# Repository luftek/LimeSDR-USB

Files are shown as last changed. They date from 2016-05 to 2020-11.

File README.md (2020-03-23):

#### Enclosure KIT for now available on eBay
##### [https://www.ebay.com/itm/113327856684](https://www.ebay.com/itm/113327856684)
##### -> More design files and photos in: [hardware/enclosure/](./hardware/enclosure/)

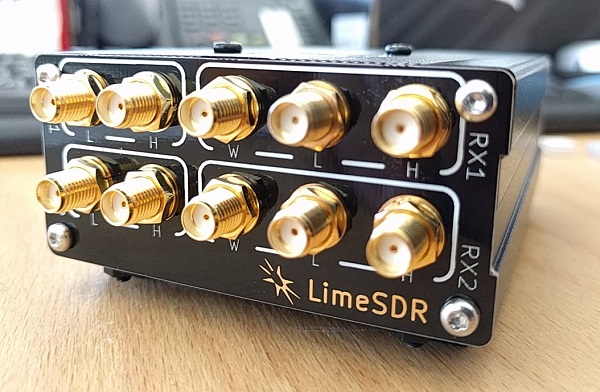
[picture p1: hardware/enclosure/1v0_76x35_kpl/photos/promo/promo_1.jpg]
Kit_promo_1


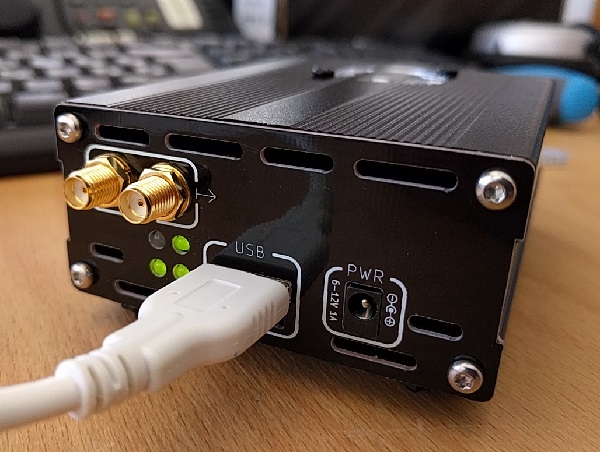
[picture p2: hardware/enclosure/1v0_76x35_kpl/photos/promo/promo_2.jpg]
Kit_promo_2


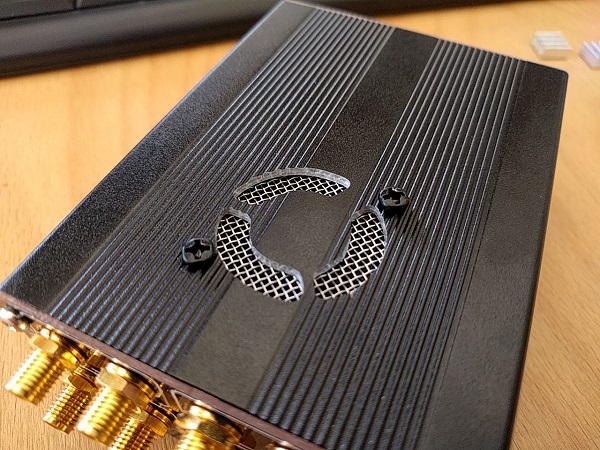
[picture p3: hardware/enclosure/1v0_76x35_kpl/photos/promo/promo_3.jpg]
Kit_promo_3


## Licensing

The hardware designs are licensed under a Creative Commons Attribution 3.0 Unported licence.

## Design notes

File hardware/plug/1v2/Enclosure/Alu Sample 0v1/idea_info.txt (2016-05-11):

Already available suitable enclosures?
Decided for higher 43mm enclosure to fit all 10 SMA connectors on front panel

Sample PCB:
1. main sample board in two parts 50x60, to see how it fits in Sample enclosure
2. Front and back panel with suitable ports, leds and dip switches

100x100 mm board samples from Dirty PCB?

TODO:
- design sample PCB to accomodate all connectors that are present currently on LimeSDR
- design Front panel
	-	10x SMA connectors
	-	status leds
- and Back panel
	-	1X SMA for clock
	-   DIP
	-   LEDs
	- 	FPGA I/O

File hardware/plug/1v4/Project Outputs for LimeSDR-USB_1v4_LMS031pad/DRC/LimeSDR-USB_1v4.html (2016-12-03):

Altium

# Design Rule Verification Report

Date: | | 2016-09-13
Time: | | 16:37:09
Elapsed Time: | | 00:03:49
Filename: | | E:\Saniok\Lime Micro\Lime PCBs\LimeSDR-USB_1v4\Altium designer design files\PCB\LimeSDR-USB_1v4.PcbDoc

Warnings: | | 12
Rule Violations: | | 0

## Summary

Warnings | Count
Unplated multi-layer pad(s) detected | 12
Total | 12

Rule Violations | Count
Component Clearance Constraint ( Horizontal Gap = -2mm, Vertical Gap = Infinite ) (InComponent('J13')),(InComponent('J14')) | 0
Component Clearance Constraint ( Horizontal Gap = -2mm, Vertical Gap = Infinite ) (InComponent('J17')),(All) | 0
Differential Pairs Uncoupled Length using the Gap Constraints (Min=0.1mm) (Max=0.2mm) (Prefered=0.1mm) and Width Constraints (Min=0.1mm) (Max=0.4mm) (Prefered=0.1mm) (InNet('FX3_XTAL_N') or InNet('FX3_XTAL_P')) | 0
Matched Lengths(Tolerance=0.5mm) (InNetClass('DDR2_1_A[0..12]')) | 0
Matched Lengths(Tolerance=0.5mm) (InNetClass('DDR2_1_DQ[0..15]')) | 0
Matched Lengths(Tolerance=0.5mm) (InNetClass('DDR2_2_A[0..12]')) | 0
Matched Lengths(Tolerance=0.5mm) (InNetClass('DDR2_2_DQ[0..15]')) | 0
Net Antennae (Tolerance=0mm) (All) | 0
Hole To Hole Clearance (Gap=0.15mm) (All),(All) | 0
Routing Layers(All) | 0
Clearance Constraint (Gap=0.1mm) (All),(All) | 0
Short-Circuit Constraint (Allowed=No) (All),(All) | 0
Un-Routed Net Constraint ( (All) ) | 0
Power Plane Connect Rule(Relief Connect )(Expansion=0.508mm) (Conductor Width=0.254mm) (Air Gap=0.254mm) (Entries=4) (All) | 0
Width Constraint (Min=0.1mm) (Max=5mm) (Preferred=0.2mm) (All) | 0
Routing Via (MinHoleWidth=0.2mm) (MaxHoleWidth=4.5mm) (PreferredHoleWidth=0.2mm) (MinWidth=0.31mm) (MaxWidth=5mm) (PreferedWidth=0.4mm) (All) | 0
Pads and Vias to follow the Drill pairs settings | 0
Hole Size Constraint (Min=0.2mm) (Max=10mm) (All) | 0
Height Constraint (Min=0mm) (Max=14.47mm) (Prefered=14.47mm) (OnTopLayer) | 0
Differential Pairs Uncoupled Length using the Gap Constraints (Min=0.1mm) (Max=0.3mm) (Prefered=0.1mm) and Width Constraints (Min=0.1mm) (Max=0.5mm) (Prefered=0.2mm) (All) | 0
Component Clearance Constraint ( Horizontal Gap = 0.01mm, Vertical Gap = 0.254mm ) (All),(All) | 0
Height Constraint (Min=0mm) (Max=2.67mm) (Prefered=2.67mm) (OnBottomLayer) | 0
Modified Polygon (Allow modified: No), (Allow shelved: No) | 0
Differential Pairs Uncoupled Length using the Gap Constraints (Min=0.1mm) (Max=0.2mm) (Prefered=0.1mm) and Width Constraints (Min=0.1mm) (Max=0.4mm) (Prefered=0.1mm) (InNetClass('DDR2_1_CK') or InNetClass('DDR2_1_CK')) | 0
Matched Lengths(Tolerance=1mm) (InNetClass('LMS_PORT1')) | 0
Matched Lengths(Tolerance=1mm) (InNetClass('LMS_PORT2')) | 0
Differential Pairs Uncoupled Length using the Gap Constraints (Min=0.1mm) (Max=0.3mm) (Prefered=0.1mm) and Width Constraints (Min=0.2mm) (Max=0.2mm) (Prefered=0.2mm) (InNetClass('FX3_DATA')) | 0
Differential Pairs Uncoupled Length using the Gap Constraints (Min=0.1mm) (Max=0.3mm) (Prefered=0.2mm) and Width Constraints (Min=0.1mm) (Max=0.3mm) (Prefered=0.2mm) (InNetClass('TX_RF')) | 0
Differential Pairs Uncoupled Length using the Gap Constraints (Min=0.1mm) (Max=0.3mm) (Prefered=0.2mm) and Width Constraints (Min=0.1mm) (Max=0.3mm) (Prefered=0.2mm) (InNetClass('RX_RF')) | 0
Width Constraint (Min=0.1mm) (Max=7mm) (Preferred=0.2mm) (All) | 0
Component Clearance Constraint ( Horizontal Gap = -1mm, Vertical Gap = Infinite ) (InComponent('LEDS1') or InComponent('LEDS2') or InComponent('LED1') or InComponent('LED4') or InComponent('LED5') or InComponent('LED8')),(InComponent('LED1') or InComponent('LED4') or InComponent('LED5') or InComponent('LED8') or InComponent('LEDS1') or InComponent('LEDS2')) | 0
Total | 0

## Warnings

Unplated multi-layer pad(s) detected

Pad Free-2(78.5mm,60.1mm) on MultiLayer on Net GND

Pad Free-3(79.7mm,60.1mm) on MultiLayer on Net GND

Pad Free-4(80.875mm,60.1mm) on MultiLayer on Net GND

Pad Free-4(80.875mm,-0.1mm) on MultiLayer on Net GND

Pad Free-3(79.7mm,-0.1mm) on MultiLayer on Net GND

Pad Free-2(78.5mm,-0.1mm) on MultiLayer on Net GND

Pad Free-2(21.5mm,-0.1mm) on MultiLayer on Net GND

Pad Free-3(20.3mm,-0.1mm) on MultiLayer on Net GND

Pad Free-4(19.125mm,-0.1mm) on MultiLayer on Net GND

Pad Free-2(21.5mm,60.1mm) on MultiLayer on Net GND

Pad Free-3(20.3mm,60.1mm) on MultiLayer on Net GND

Pad Free-4(19.125mm,60.1mm) on MultiLayer on Net GND

Back to top

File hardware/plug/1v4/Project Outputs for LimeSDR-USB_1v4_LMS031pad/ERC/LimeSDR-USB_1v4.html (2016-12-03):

Altium

# Electrical Rule Check Report

Date: | | 2016-09-13
Time: | | 16:41:00
Filename: | | E:\Saniok\Lime Micro\Lime PCBs\LimeSDR-USB_1v4\Altium designer design files\Project Outputs for LimeSDR-USB_1v4\ERC\LimeSDR-USB_1v4.html

Class | Document | Message
Warning | 15_BoardPowerSupply.SchDoc | FPGA_LED1_R contains IO Pin and Power Pin objects (Pin LED1-3,Pin IC8-E3,Pin LEDS1-K1)
Warning | 15_BoardPowerSupply.SchDoc | FPGA_LED2_R contains IO Pin and Power Pin objects (Pin LED7-3,Pin IC8-E1,Pin LEDS1-K2)
Warning | 15_BoardPowerSupply.SchDoc | FX3_LED_R contains IO Pin and Power Pin objects (Pin LED2-3,Pin IC8-H5,Pin LEDS2-K1)

Warning

15_BoardPowerSupply.SchDoc

GND contains IO Pin and Power Pin objects (Pin LED8-3,Pin IC19-4,Pin IC22-5,Pin IC13-A1,Pin IC8-A1,Pin IC12-A3,Pin IC11-A3,Pin IC12-A7,Pin IC11-A7,Pin IC13-A8,Pin IC8-A19,Pin IC8-A22,Pin IC8-AA2,Pin IC8-AA22,Pin IC8-AB1,Pin IC8-AB6,Pin IC8-AB22,Pin IC12-B2,Pin IC11-B2,Pin IC8-B5,Pin IC13-B7,Pin IC13-B8,Pin IC12-B8,Pin IC11-B8,Pin IC13-B9,Pin IC8-B19,Pin IC8-C5,Pin IC8-C9,Pin IC8-C10,Pin IC8-C11,Pin IC8-C12,Pin IC8-C14,Pin IC8-C15,Pin IC8-C16,Pin IC8-C18,Pin IC12-D2,Pin IC11-D2,Pin IC8-D3,Pin IC8-D6,Pin IC13-D8,Pin IC12-D8,Pin IC11-D8,Pin IC8-D8,Pin IC8-D15,Pin IC8-D17,Pin IC8-D20,Pin IC13-E2,Pin IC12-E3,Pin IC11-E3,Pin IC12-E7,Pin IC11-E7,Pin IC8-E9,Pin IC8-E13,Pin IC8-E18,Pin IC8-E20,Pin IC12-F2,Pin IC11-F2,Pin IC8-F3,Pin IC8-F5,Pin IC12-F8,Pin IC11-F8,Pin IC8-F12,Pin IC8-F19,Pin IC8-F20,Pin IC13-G1,Pin IC8-G2,Pin IC13-G11,Pin IC8-G20,Pin IC12-H2,Pin IC11-H2,Pin IC8-H3,Pin IC12-H8,Pin IC11-H8,Pin IC8-H12,Pin IC8-H13,Pin IC8-H17,Pin IC8-H18,Pin IC12-J3,Pin IC11-J3,Pin IC12-J7,Pin IC11-J7,Pin IC8-J9,Pin IC8-J15,Pin IC8-J18,Pin IC8-J19,Pin LEDS2-K2,Pin IC13-K3,Pin IC8-K3,Pin IC13-K4,Pin IC8-K10,Pin IC8-K11,Pin IC8-K12,Pin IC8-K13,Pin IC8-K16,Pin IC8-K19,Pin IC13-L1,Pin IC13-L2,Pin IC13-L3,Pin IC13-L6,Pin IC8-L10,Pin IC13-L11,Pin IC8-L11,Pin IC8-L12,Pin IC8-L13,Pin IC8-L15,Pin IC8-L20,Pin IC8-M10,Pin IC8-M11,Pin IC8-M12,Pin IC8-M13,Pin IC8-M16,Pin IC12-N1,Pin IC11-N1,Pin IC8-N3,Pin IC8-N10,Pin IC8-N11,Pin IC8-N12,Pin IC8-N13,Pin IC8-N15,Pin IC8-P8,Pin IC12-P9,Pin IC11-P9,Pin IC8-P19,Pin IC8-P20,Pin IC8-R3,Pin IC8-R9,Pin IC8-R11,Pin IC8-R13,Pin IC8-R17,Pin IC8-T17,Pin IC8-T20,Pin IC8-U3,Pin IC8-U5,Pin IC8-V18,Pin IC8-V20,Pin IC8-W3,Pin IC8-W19,Pin IC8-Y5,Pin IC8-Y9,Pin IC8-Y11,Pin IC8-Y12,Pin IC8-Y15,Pin IC8-Y16,Pin IC8-Y18,Pin IC8-Y20)
Warning | 10_FPGA_misc.SchDoc | Net FPGA_JTAG_TCK has no driving source (Pin IC8-L2,Pin J11-1,Pin R62-1)
Warning | 10_FPGA_misc.SchDoc | Net FPGA_JTAG_TDI has no driving source (Pin IC8-L5,Pin J11-9,Pin R58-1)
Warning | 10_FPGA_misc.SchDoc | Net FPGA_JTAG_TMS has no driving source (Pin IC8-L1,Pin J11-5,Pin R55-1)
Warning | 12_USB3_0_device.SchDoc | Net FPGA_NCONFIG has no driving source (Pin IC8-K5,Pin R105-2,Pin R106-2)
Warning | 12_USB3_0_device.SchDoc | Net FX3_FSLC0 has no driving source (Pin IC13-B2,Pin R125-2)
Warning | 12_USB3_0_device.SchDoc | Net FX3_FSLC1 has no driving source (Pin IC13-B4,Pin R127-2)
Warning | 12_USB3_0_device.SchDoc | Net FX3_FSLC2 has no driving source (Pin IC13-E6,Pin R128-2)
Warning | 12_USB3_0_device.SchDoc | Net FX3_JTAG_TCK has no driving source (Pin IC13-F6,Pin J16-4)
Warning | 12_USB3_0_device.SchDoc | Net FX3_JTAG_TDI has no driving source (Pin IC13-E7,Pin J16-8)
Warning | 12_USB3_0_device.SchDoc | Net FX3_JTAG_TMS has no driving source (Pin IC13-E8,Pin J16-2)
Warning | 12_USB3_0_device.SchDoc | Net FX3_JTAG_TRST has no driving source (Pin IC13-B11,Pin R124-1)
Warning | 12_USB3_0_device.SchDoc | Net FX3_OTG_ID has no driving source (Pin IC13-C9,Pin J15-4,Pin R92-2)
Warning | 12_USB3_0_device.SchDoc | Net FX3_PCLK has no driving source (Pin IC8-T21,Pin R98-1)
Warning | 12_USB3_0_device.SchDoc | Net FX3_RST has no driving source (Pin C278-1,Pin IC13-C5,Pin R118-1,Pin R120-2,Pin SW1-2)
Warning | 12_USB3_0_device.SchDoc | Net FX3_USB_SSRX_N has no driving source (Pin IC13-A4,Pin IC14-4,Pin IC14-7,Pin J15-9)
Warning | 12_USB3_0_device.SchDoc | Net FX3_USB_SSRX_P has no driving source (Pin IC13-A3,Pin IC14-5,Pin IC14-6,Pin J15-10)
Warning | 14_Clocks.SchDoc | Net LMK_CLK has no driving source (Pin IC8-B12,Pin IC20-15)
Warning | 04_LMS7002M_Misc.SchDoc | Net LMS_MCLK1 has no driving source (Pin IC1-AB34,Pin IC8-G21)
Warning | 10_FPGA_misc.SchDoc | Net LMS_MCLK2 has no driving source (Pin IC1-P34,Pin IC8-B11)
Warning | 10_FPGA_misc.SchDoc | Net MSEL0 has no driving source (Pin IC8-M17,Pin R51-1,Pin R52-2)
Warning | 10_FPGA_misc.SchDoc | Net MSEL1 has no driving source (Pin IC8-L18,Pin R53-1,Pin R54-2)
Warning | 10_FPGA_misc.SchDoc | Net MSEL2 has no driving source (Pin IC8-L17,Pin R56-1,Pin R57-2)
Warning | 10_FPGA_misc.SchDoc | Net MSEL3 has no driving source (Pin IC8-K20,Pin R59-1,Pin R60-2)
Warning | 05_LMS7002M_RF1.SchDoc | Net NetC10_1 has no driving source (Pin C10-1,Pin IC4-5)
Warning | 05_LMS7002M_RF1.SchDoc | Net NetC19_1 has no driving source (Pin C19-1,Pin IC5-5)
Warning | 06_LMS7002M_RF2.SchDoc | Net NetC30_1 has no driving source (Pin C30-1,Pin IC6-5)
Warning | 06_LMS7002M_RF2.SchDoc | Net NetC39_1 has no driving source (Pin C39-1,Pin IC7-5)
Warning | 15_BoardPowerSupply.SchDoc | Net NetC383_2 has no driving source (Pin C383-2,Pin FR58-2,Pin IC28-5,Pin IC28-8)
Warning | 15_BoardPowerSupply.SchDoc | Net NetC397_2 has no driving source (Pin C397-2,Pin FR59-2,Pin IC30-5,Pin IC30-8)
Warning | 15_BoardPowerSupply.SchDoc | Net NetC404_2 has no driving source (Pin C404-2,Pin FR60-2,Pin IC33-5,Pin IC33-8)
Warning | 15_BoardPowerSupply.SchDoc | Net NetC420_2 has no driving source (Pin C420-2,Pin FR62-2,Pin IC36-3)
Warning | 15_BoardPowerSupply.SchDoc | Net NetC421_2 has no driving source (Pin C421-2,Pin IC36-1,Pin R211-2,Pin R212-1)
Warning | 15_BoardPowerSupply.SchDoc | Net NetIC36_8 has no driving source (Pin IC36-8,Pin R209-2,Pin R210-2)
Warning | 14_Clocks.SchDoc | Net SI_CLK0 has no driving source (Pin IC8-T2,Pin IC24-13)
Warning | 14_Clocks.SchDoc | Net SI_CLK1 has no driving source (Pin IC8-AA12,Pin IC24-12)
Warning | 14_Clocks.SchDoc | Net SI_CLK2 has no driving source (Pin IC8-AB12,Pin IC24-9)
Warning | 14_Clocks.SchDoc | Net SI_CLK3 has no driving source (Pin IC8-T22,Pin IC24-8)
Warning | 14_Clocks.SchDoc | Net SI_CLK5 has no driving source (Pin IC8-G1,Pin IC24-17)
Warning | 14_Clocks.SchDoc | Net SI_CLK6 has no driving source (Pin IC8-AA11,Pin IC24-16)
Warning | 14_Clocks.SchDoc | Net SI_CLK7 has no driving source (Pin IC8-AB11,Pin IC24-15)

Back to top

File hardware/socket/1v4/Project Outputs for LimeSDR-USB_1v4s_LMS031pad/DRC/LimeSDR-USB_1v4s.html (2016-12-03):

Altium

# Design Rule Verification Report

Date: | | 2016-09-13
Time: | | 17:07:08
Elapsed Time: | | 00:03:37
Filename: | | E:\Saniok\Lime Micro\Lime PCBs\LimeSDR-USB_1v4s\Altium designer design files\PCB\LimeSDR-USB_1v4s.PcbDoc

Warnings: | | 12
Rule Violations: | | 0

## Summary

Warnings | Count
Unplated multi-layer pad(s) detected | 12
Total | 12

Rule Violations | Count
Component Clearance Constraint ( Horizontal Gap = -1mm, Vertical Gap = Infinite ) (InComponent('LEDS1') or InComponent('LEDS2') or InComponent('LED1') or InComponent('LED4') or InComponent('LED5') or InComponent('LED8')),(InComponent('LED1') or InComponent('LED4') or InComponent('LED5') or InComponent('LED8') or InComponent('LEDS1') or InComponent('LEDS2')) | 0
Width Constraint (Min=0.1mm) (Max=7mm) (Preferred=0.2mm) (All) | 0
Differential Pairs Uncoupled Length using the Gap Constraints (Min=0.1mm) (Max=0.3mm) (Prefered=0.2mm) and Width Constraints (Min=0.1mm) (Max=0.3mm) (Prefered=0.2mm) (InNetClass('RX_RF')) | 0
Differential Pairs Uncoupled Length using the Gap Constraints (Min=0.1mm) (Max=0.3mm) (Prefered=0.2mm) and Width Constraints (Min=0.1mm) (Max=0.3mm) (Prefered=0.2mm) (InNetClass('TX_RF')) | 0
Differential Pairs Uncoupled Length using the Gap Constraints (Min=0.1mm) (Max=0.3mm) (Prefered=0.1mm) and Width Constraints (Min=0.2mm) (Max=0.2mm) (Prefered=0.2mm) (InNetClass('FX3_DATA')) | 0
Matched Lengths(Tolerance=1mm) (InNetClass('LMS_PORT2')) | 0
Matched Lengths(Tolerance=1mm) (InNetClass('LMS_PORT1')) | 0
Differential Pairs Uncoupled Length using the Gap Constraints (Min=0.1mm) (Max=0.2mm) (Prefered=0.1mm) and Width Constraints (Min=0.1mm) (Max=0.4mm) (Prefered=0.1mm) (InNetClass('DDR2_1_CK') or InNetClass('DDR2_1_CK')) | 0
Modified Polygon (Allow modified: No), (Allow shelved: No) | 0
Height Constraint (Min=0mm) (Max=2.67mm) (Prefered=2.67mm) (OnBottomLayer) | 0
Component Clearance Constraint ( Horizontal Gap = 0.01mm, Vertical Gap = 0.254mm ) (All),(All) | 0
Differential Pairs Uncoupled Length using the Gap Constraints (Min=0.1mm) (Max=0.3mm) (Prefered=0.1mm) and Width Constraints (Min=0.1mm) (Max=0.5mm) (Prefered=0.2mm) (All) | 0
Height Constraint (Min=0mm) (Max=14.47mm) (Prefered=14.47mm) (OnTopLayer) | 0
Hole Size Constraint (Min=0.2mm) (Max=10mm) (All) | 0
Pads and Vias to follow the Drill pairs settings | 0
Routing Via (MinHoleWidth=0.2mm) (MaxHoleWidth=4.5mm) (PreferredHoleWidth=0.2mm) (MinWidth=0.31mm) (MaxWidth=5mm) (PreferedWidth=0.4mm) (All) | 0
Width Constraint (Min=0.1mm) (Max=5mm) (Preferred=0.2mm) (All) | 0
Power Plane Connect Rule(Relief Connect )(Expansion=0.508mm) (Conductor Width=0.254mm) (Air Gap=0.254mm) (Entries=4) (All) | 0
Un-Routed Net Constraint ( (All) ) | 0
Short-Circuit Constraint (Allowed=No) (All),(All) | 0
Clearance Constraint (Gap=0.1mm) (All),(All) | 0
Routing Layers(All) | 0
Hole To Hole Clearance (Gap=0.15mm) (All),(All) | 0
Net Antennae (Tolerance=0mm) (All) | 0
Matched Lengths(Tolerance=0.5mm) (InNetClass('DDR2_2_DQ[0..15]')) | 0
Matched Lengths(Tolerance=0.5mm) (InNetClass('DDR2_2_A[0..12]')) | 0
Matched Lengths(Tolerance=0.5mm) (InNetClass('DDR2_1_DQ[0..15]')) | 0
Matched Lengths(Tolerance=0.5mm) (InNetClass('DDR2_1_A[0..12]')) | 0
Differential Pairs Uncoupled Length using the Gap Constraints (Min=0.1mm) (Max=0.2mm) (Prefered=0.1mm) and Width Constraints (Min=0.1mm) (Max=0.4mm) (Prefered=0.1mm) (InNet('FX3_XTAL_N') or InNet('FX3_XTAL_P')) | 0
Component Clearance Constraint ( Horizontal Gap = -2mm, Vertical Gap = Infinite ) (InComponent('J17')),(All) | 0
Component Clearance Constraint ( Horizontal Gap = -2mm, Vertical Gap = Infinite ) (InComponent('J13')),(InComponent('J14')) | 0
Total | 0

## Warnings

Unplated multi-layer pad(s) detected

Pad Free-4(19.125mm,60.1mm) on MultiLayer on Net GND

Pad Free-3(20.3mm,60.1mm) on MultiLayer on Net GND

Pad Free-2(21.5mm,60.1mm) on MultiLayer on Net GND

Pad Free-4(19.125mm,-0.1mm) on MultiLayer on Net GND

Pad Free-3(20.3mm,-0.1mm) on MultiLayer on Net GND

Pad Free-2(21.5mm,-0.1mm) on MultiLayer on Net GND

Pad Free-2(78.5mm,-0.1mm) on MultiLayer on Net GND

Pad Free-3(79.7mm,-0.1mm) on MultiLayer on Net GND

Pad Free-4(80.875mm,-0.1mm) on MultiLayer on Net GND

Pad Free-4(80.875mm,60.1mm) on MultiLayer on Net GND

Pad Free-3(79.7mm,60.1mm) on MultiLayer on Net GND

Pad Free-2(78.5mm,60.1mm) on MultiLayer on Net GND

Back to top

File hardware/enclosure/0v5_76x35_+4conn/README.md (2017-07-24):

[eBay listing](http://www.ebay.com/itm/-/112088499793) 

### fits great :)

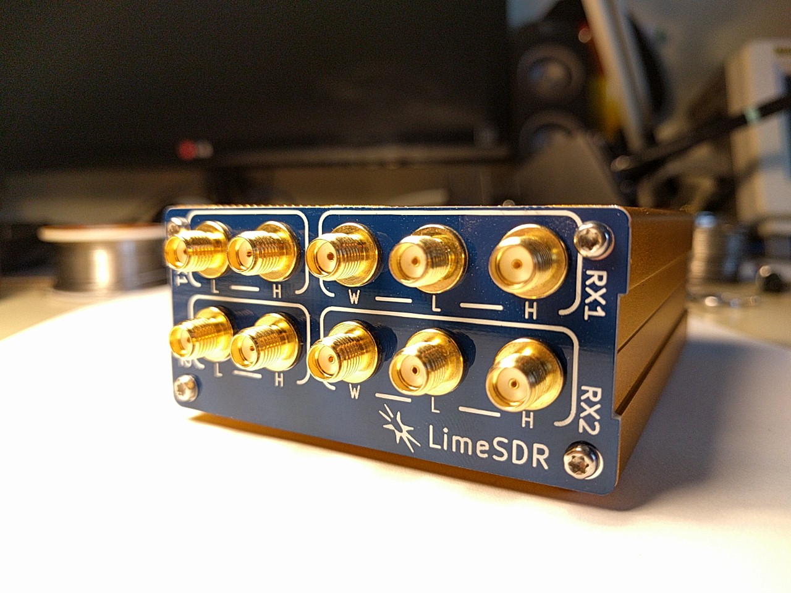
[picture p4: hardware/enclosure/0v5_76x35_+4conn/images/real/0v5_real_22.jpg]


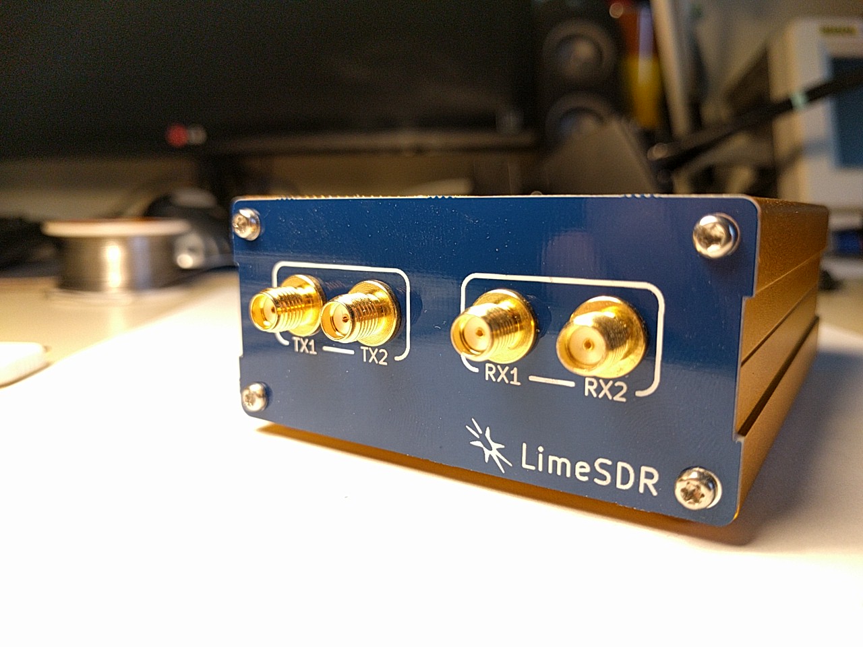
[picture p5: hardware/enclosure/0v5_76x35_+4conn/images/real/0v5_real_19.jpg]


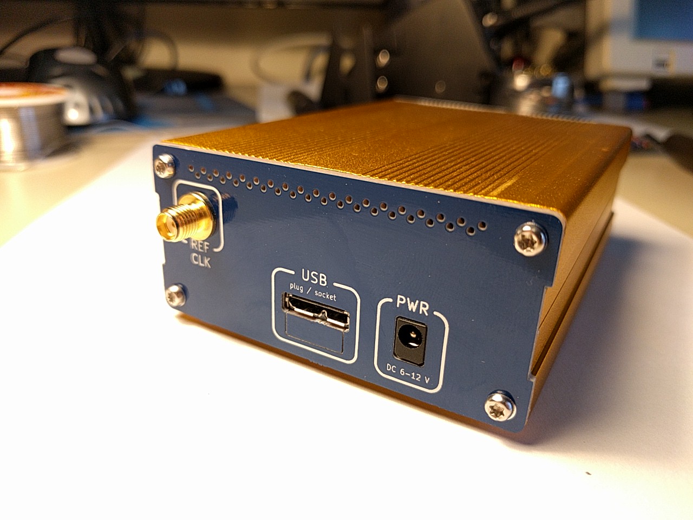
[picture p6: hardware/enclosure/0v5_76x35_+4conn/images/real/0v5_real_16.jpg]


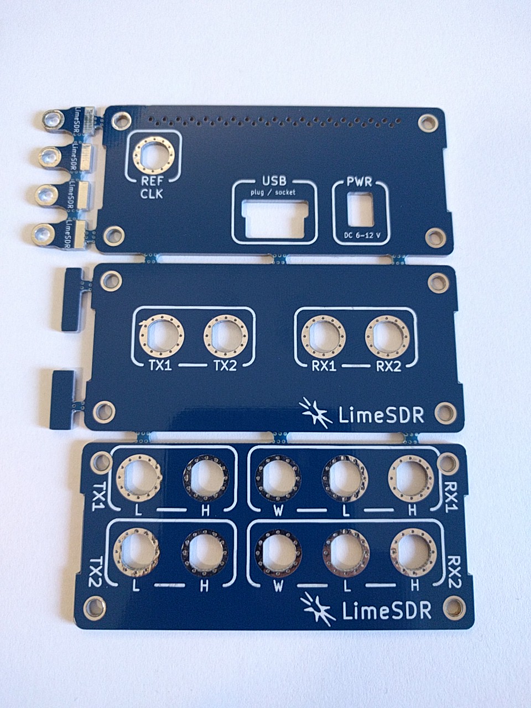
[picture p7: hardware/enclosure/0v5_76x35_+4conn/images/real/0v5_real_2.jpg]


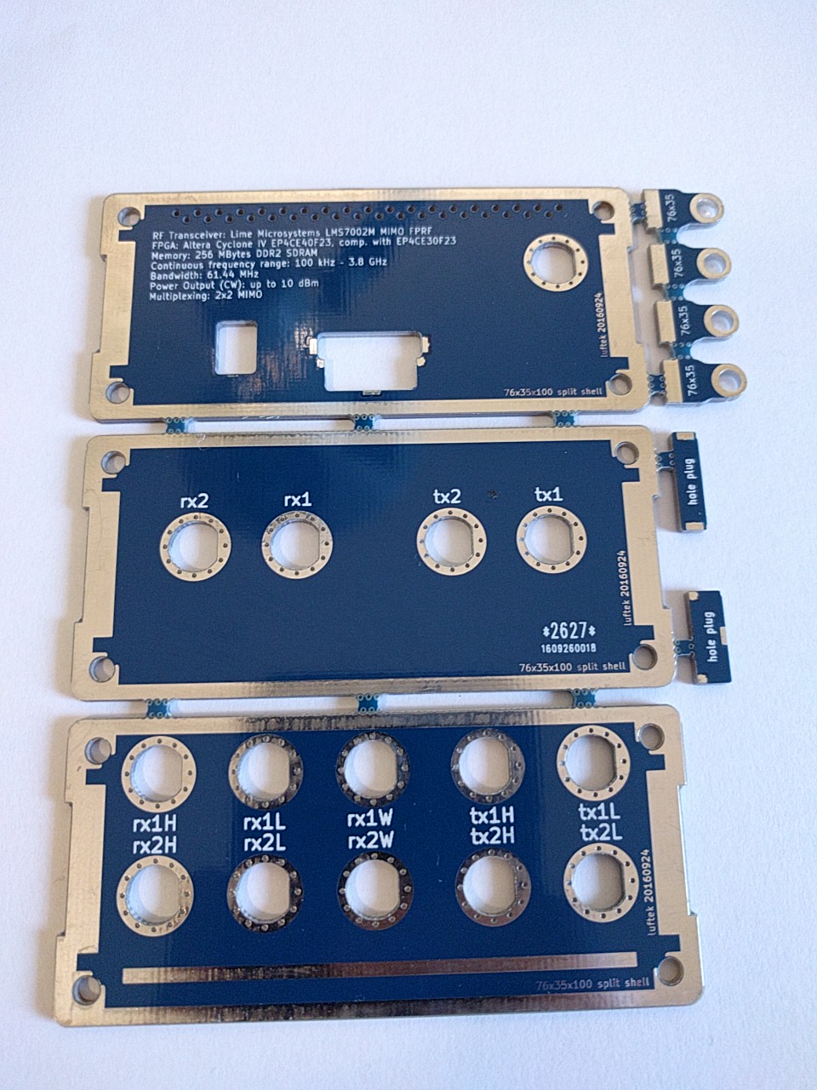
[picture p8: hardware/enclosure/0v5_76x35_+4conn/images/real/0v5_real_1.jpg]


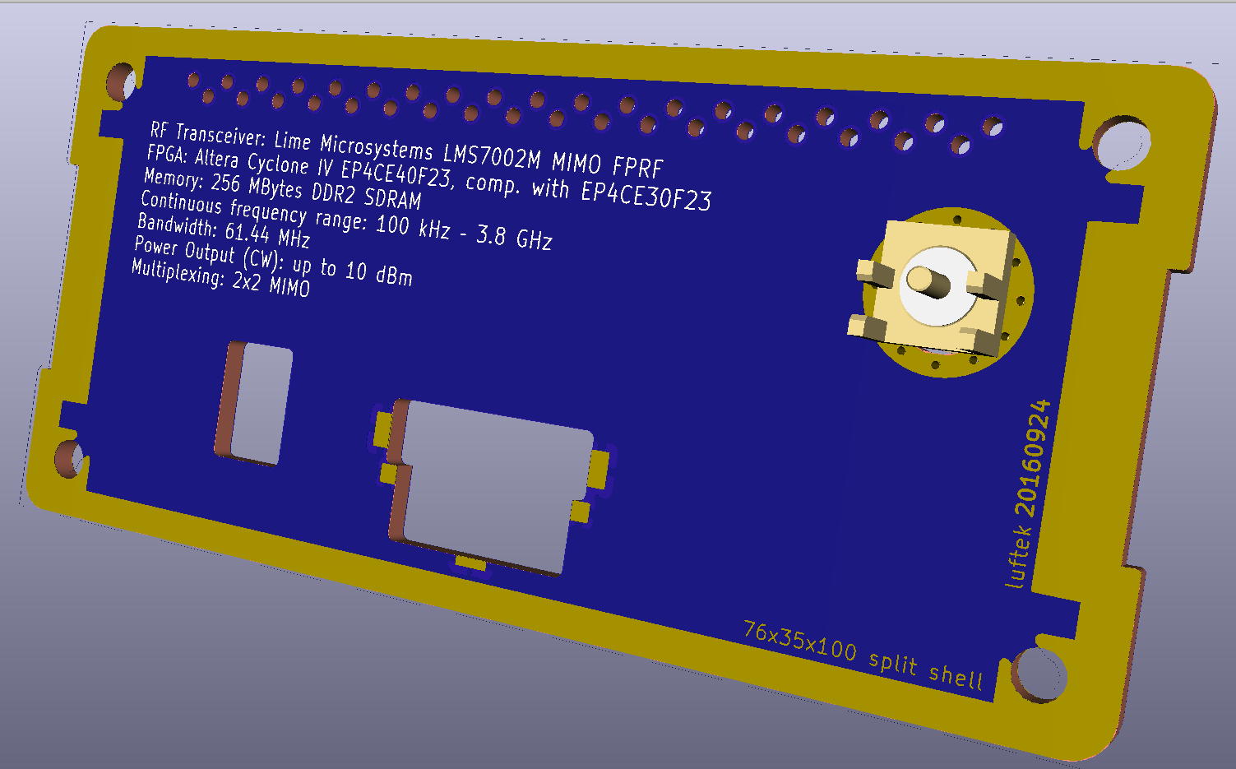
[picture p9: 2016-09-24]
hardware/enclosure/0v5_76x35_+4conn/images/design/2016-09-24_17_07_07-3D_Viewer.png

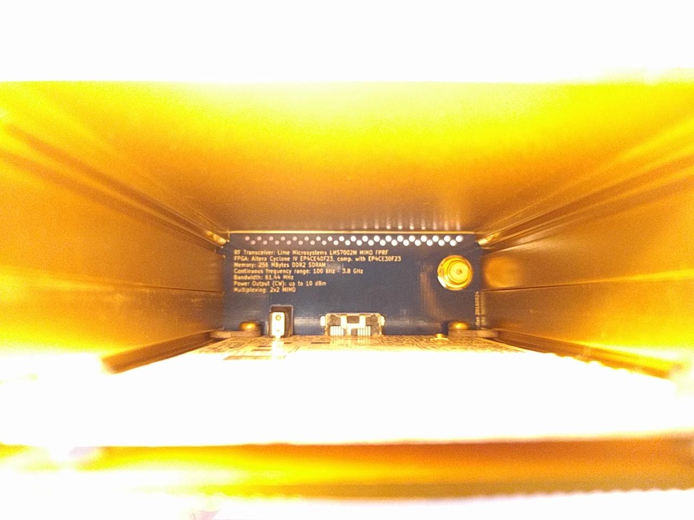
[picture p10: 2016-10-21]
hardware/enclosure/0v5_76x35_+4conn/images/real/0v5_real_21.jpg

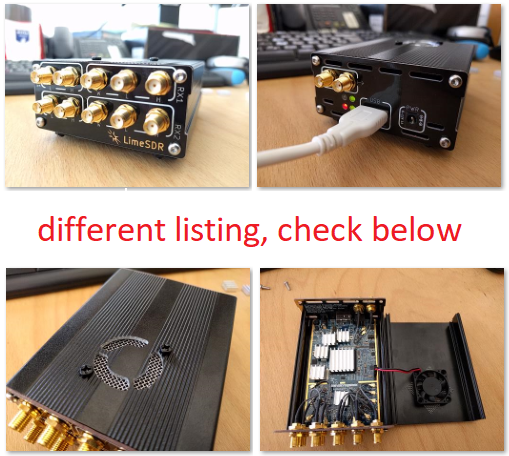
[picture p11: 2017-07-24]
hardware/enclosure/1v0_76x35_kpl/photos/promo/promo_.png

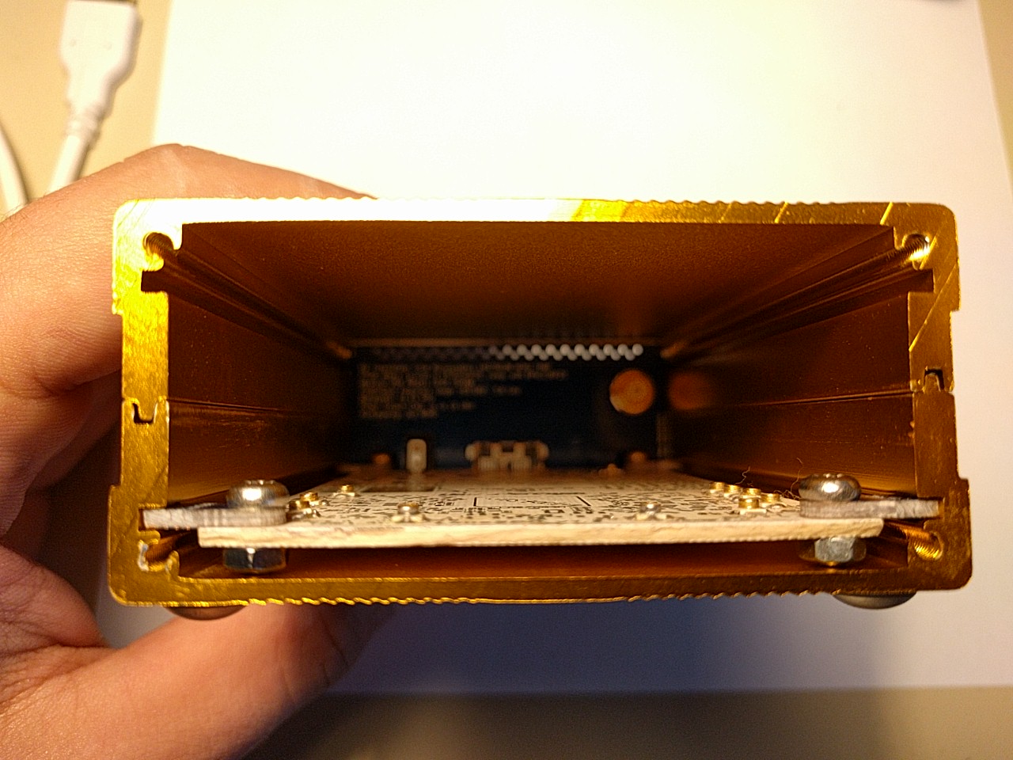
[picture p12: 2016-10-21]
hardware/enclosure/0v5_76x35_+4conn/images/real/0v5_real_20.jpg

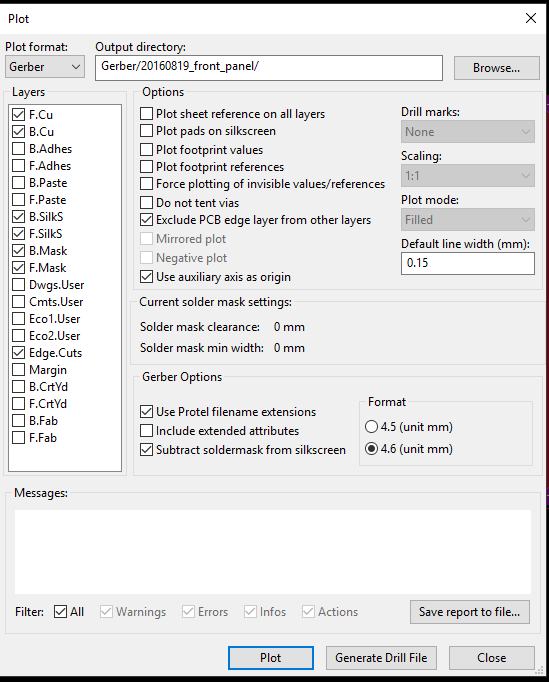
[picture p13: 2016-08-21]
hardware/enclosure/0v5_76x35_+4conn/images/design/2016-08-19 16_58_14-Pcbnew (2016-07-22 BZR 6991, Git 146a78a)-product C__Users_Borec_Documents_GitHu.png

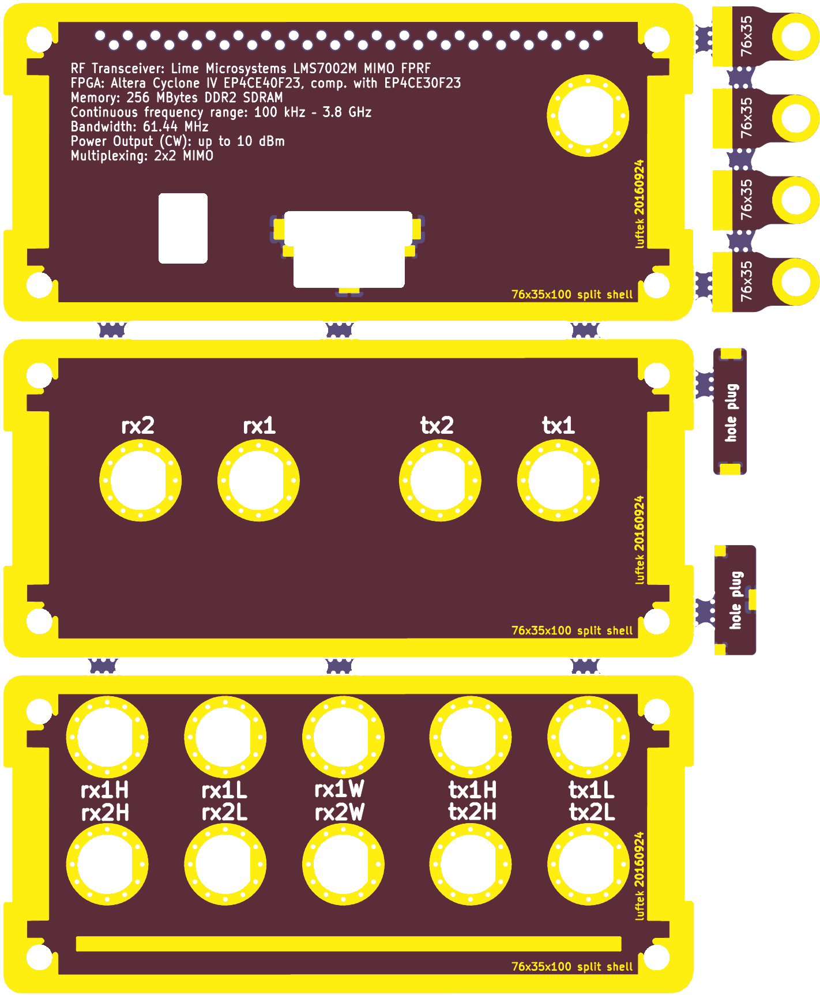
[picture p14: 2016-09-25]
hardware/enclosure/0v5_76x35_+4conn/images/design/20160924_combined_Combined_Top.png

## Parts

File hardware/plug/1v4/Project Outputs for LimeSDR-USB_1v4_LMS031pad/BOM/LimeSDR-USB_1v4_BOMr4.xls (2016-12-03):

Item # | Comment | Quantity | Designator | Footprint | Manufacturer | Manufacturer Part Number 1 | Supplier 1 | Supplier Part Number 1 | Part Description | Assembly Info
1 | 10pF, 25V | 4 | C1, C361, C362, C363 | CAP0402 | AVX | 04023A100JAT2A | Farnell | 2332478RL | 10pF ±5% 25V C0G, NP0 Ceramic Capacitor -55°C ~ 125°C Surface Mount, MLCC 0402 (1005 Metric) 0.039" L x 0.020" W (1.00mm x 0.50mm)
2 | 1uF, 10V | 22 | C2, C3, C118, C123, C130, C135, C140, C145, C242, C267, C326, C329, C333, C334, C341, C380, C382, C388, C394, C396, C403, C408 | CAP0402 | TDK | GRM155R61A105KE15J | Newark | 490-6298-2-ND | 1µF ±10% 10V X5R Ceramic Capacitor -55°C ~ 85°C Surface Mount, MLCC 0402 (1005 Metric) 0.039" L x 0.020" W (1.00mm x 0.50mm) | NF(C341)
3 | 100nF, 16V | 193 | C4, C5, C6, C7, C8, C24, C25, C26, C27, C28, C103, C104, C105, C106, C107, C108, C109, C110, C111, C112, C113, C114, C119, C124, C125, C131, C136, C141, C146, C147, C148, C149, C150, C151, C152, C153, C154, C155, C156, C157, C158, C159, C160, C161, C162, C163, C164, C165, C166, C167, C168, C169, C170, C171, C172, C173, C174, C175, C176, C177, C178, C179, C180, C181, C182, C183, C184, C185, C186, C187, C188, C189, C190, C191, C192, C193, C194, C195, C196, C197, C198, C199, C200, C201, C202, C203, C204, C205, C206, C207, C208, C209, C210, C211, C212, C213, C214, C215, C216, C217, C218, C219, C220, C221, C222, C223, C224, C226, C227, C228, C229, C232, C233, C234, C235, C236, C237, C238, C239, C243, C244, C246, C247, C248, C249, C251, C252, C253, C254, C257, C258, C259, C260, C261, C262, C263, C264, C268, C269, C270, C271, C272, C274, C276, C278, C279, C280, C281, C282, C284, C285, C288, C291, C293, C296, C299, C300, C302, C305, C306, C307, C308, C309, C310, C311, C312, C321, C322, C323, C327, C328, C330, C335, C338, C342, C345, C346, C352, C359, C360, C364, C365, C366, C372, C373, C378, C381, C395, C399, MN5, MN8, MN33, MN36 | CAP0402 | Murata Electronics | GRM155R71C104KA88D | Mouser | 81-GRM155R71C104KA88 | 0.10µF ±10% 16V X7R Ceramic Capacitor -55°C ~ 125°C Surface Mount, MLCC 0402 (1005 Metric) 0.039" L x 0.020" W (1.00mm x 0.50mm)
4 | 100pF, 50V | 35 | C9, C10, C13, C15, C16, C17, C18, C19, C20, C29, C30, C33, C35, C36, C37, C38, C39, C40, C331, C332, C336, C337, C339, C340, C343, C344, C347, C348, C349, C350, C351, MN25, MN28, MN53, MN56 | CAP0402 | Yageo | CC0402JRNPO9BN101 | Digi-Key | 311-1024-1-ND | 100pF ±5% 50V C0G, NP0 Ceramic Capacitor -55°C ~ 125°C Surface Mount, MLCC 0402 (1005 Metric) 0.039" L x 0.020" W (1.00mm x 0.50mm)
5 | 47pF | 10 | C11, C12, C21, C22, C31, C32, C41, C42, C324, C325 | CAP0402 | TDK Corporation | C1005C0G1H470F050BA | Digi-Key | 445-5361-1-ND | 47pF ±1% 50V C0G, NP0 Ceramic Capacitor -55°C ~ 125°C Surface Mount, MLCC 0402 (1005 Metric) 0.039" L x 0.020" W (1.00mm x 0.50mm) | NF(C324 C325)
6 | 470pF, 50V | 4 | C14, C23, C34, C43 | CAP0402 | TDK Corporation | C1005C0G1H471J050BA | Digi-Key | 445-2656-6-ND | 470pF ±5% 50V C0G, NP0 Ceramic Capacitor -55°C ~ 125°C Surface Mount, MLCC 0402 (1005 Metric) 0.039" L x 0.020" W (1.00mm x 0.50mm)
7 | 1uF, 20% | 50 | C44, C46, C48, C50, C52, C54, C56, C58, C60, C62, C63, C64, C65, C66, C67, C68, C69, C70, C71, C72, C73, C74, C75, C76, C77, C78, C79, C80, C81, C82, C83, C84, C85, C86, C87, C88, C89, C90, C91, C92, C93, C94, C95, C96, C97, C98, C99, C100, C101, C102 | CAP0201 | TDK Corporation | C0603X5R0J105M030BC | Digi-Key | 445-8008-1-ND | 1µF ±20% 6.3V X5R Ceramic Capacitor -55°C ~ 85°C Surface Mount, MLCC 0201 (0603 Metric) 0.024" L x 0.012" W (0.60mm x 0.30mm)
8 | 1nF, 10% | 9 | C45, C47, C49, C51, C53, C55, C57, C59, C61 | CAP0201 | TDK Corporation | C0603X7R1E102K030BA | Digi-Key | 445-7275-1-ND | 1000pF ±10% 25V X7R Ceramic Capacitor -55°C ~ 125°C Surface Mount, MLCC 0201 (0603 Metric) 0.024" L x 0.012" W (0.60mm x 0.30mm)
9 | 220uF, 4V | 6 | C115, C120, C126, C245, C406, C407 | CAP1206 | Murata Electronics North America | GRM31CR60G227ME11L | Digi-Key | 490-9774-1-ND | 220µF ±20% 4V X5R Ceramic Capacitor -55°C ~ 85°C Surface Mount, MLCC 1206 (3216 Metric) 0.126" L x 0.063" W (3.20mm x 1.60mm)
10 | 10uF, 6.3V | 14 | C116, C121, C128, C133, C138, C143, C240, C265, C295, C387, C392, C393, C415, C417 | CAP0603 | Yageo | CC0603MRX5R5BB106 | Digi-Key | 311-1448-2-ND | 10µF ±20% 6.3V X5R Ceramic Capacitor -55°C ~ 85°C Surface Mount, MLCC 0603 (1608 Metric) 0.063" L x 0.031" W (1.60mm x 0.80mm)
11 | 4.7uF, 6.3V | 22 | C117, C122, C129, C134, C139, C144, C241, C266, C376, C377, C383, C384, C397, C398, C401, C402, C404, C405, C409, C410, C414, C418 | CAP0402 | Murata Electronics North America | GRM155R60J475ME87D | Digi-Key | 490-5408-1-ND | 4.7µF ±20% 6.3V X5R Ceramic Capacitor -55°C ~ 85°C Surface Mount, MLCC 0402 (1005 Metric) 0.039" L x 0.020" W (1.00mm x 0.50mm)
12 | 100uF, 6.3V | 6 | C127, C132, C137, C142, C385, C386 | CAP1206 | Murata Electronics North America | GRM31CR60J107ME39L. | Farnell | 1735535 | 100µF ±20% 6.3V X5R Ceramic Capacitor -55°C ~ 85°C Surface Mount, MLCC 1206 (3216 Metric) 0.126" L x 0.063" W (3.20mm x 1.60mm) | NF(C142)
13 | 0.1uF | 6 | C225, C230, C231, C250, C255, C256 | CKCA43X7R1C104M100AA | TDK | CKCA43X7R1C104M100AA | Mouser | 810-CKCA43X7R1C104M | CAP ARRAY 0.1UF 16V X7R 1206
14 | 1uF, 16V | 1 | C273 | CAP0603 | Taiyo Yuden | EMK107B7105KA-T | Digi-Key | 587-1241-6-ND | 1µF ±10% 16V X7R Ceramic Capacitor -55°C ~ 125°C Surface Mount, MLCC 0603 (1608 Metric) 0.063" L x 0.031" W (1.60mm x 0.80mm)
15 | 13pF, 5% | 2 | C275, C277 | CAP0402 | Murata Electronics North America | GRM1555C1H130JA01D | Digi-Key | 490-5925-2-ND | 13pF ±5% 50V C0G, NP0 Ceramic Capacitor -55°C ~ 125°C Surface Mount, MLCC 0402 (1005 Metric) 0.039" L x 0.020" W (1.00mm x 0.50mm)
16 | 22uF, 10V | 6 | C283, C290, C298, C301, C303, C304 | CAP0603 | TDK | C1608X5R1A226M080AC | Mouser | 810-C1608X5R1A226M | 22µF ±20% 10V X5R Ceramic Capacitor -55°C ~ 85°C Surface Mount, MLCC 0603 (1608 Metric) 0.063" L x 0.031" W (1.60mm x 0.80mm)
17 | 10nF, 10% | 14 | C286, C287, C289, C292, C294, C297, C313, C314, C315, C316, C317, C318, C319, C320 | CAP0402 | Yageo | CC0402KRX7R9BB103 | Digi-Key | 311-1349-2-ND | 10000pF ±10% 50V X7R Ceramic Capacitor -55°C ~ 125°C Surface Mount, MLCC 0402 (1005 Metric) 0.039" L x 0.020" W (1.00mm x 0.50mm)
18 | 1nF, 10% | 2 | C353, C354 | CAP0402 | Murata Electronics | GCM155R71H102KA37D | Mouser | 81-GCM155R71H102KA7D | 1000pF ±10% 50V X7R Ceramic Capacitor -55°C ~ 125°C Surface Mount, MLCC 0402 (1005 Metric) 0.039" L x 0.020" W (1.00mm x 0.50mm)
19 | 22pF, 5% | 3 | C355, C356, C357 | CAP0402 | Yageo | CC0402JRNPO9BN220 | Digi-Key | 311-1018-2-ND | 22pF ±5% 50V C0G, NP0 Ceramic Capacitor -55°C ~ 125°C Surface Mount, MLCC 0402 (1005 Metric) 0.039" L x 0.020" W (1.00mm x 0.50mm)
20 | 220pF, 10% | 1 | C358 | CAP0402 | Yageo | CC0402KRX7R9BB221 | Digi-Key | 311-1035-2-ND | 220pF ±10% 50V X7R Ceramic Capacitor -55°C ~ 125°C Surface Mount, MLCC 0402 (1005 Metric) 0.039" L x 0.020" W (1.00mm x 0.50mm)
21 | 10uF, 25V | 11 | C367, C368, C369, C370, C371, C374, C379, C400, C419, C420, C421 | CAP0603 | Murata Electronics North America | GRM188R61E106MA73D | Digi-Key | 490-7202-2-ND | 10µF ±20% 25V X5R Ceramic Capacitor -55°C ~ 85°C Surface Mount, MLCC 0603 (1608 Metric) 0.063" L x 0.031" W (1.60mm x 0.80mm)
22 | 10uF, 16V | 2 | C375, C416 | CAP0603 | Yageo | GRM188R61C106MA73D | Digi-Key | 490-7201-2-ND | 10µF ±20% 16V X5R Ceramic Capacitor -55°C ~ 85°C Surface Mount, MLCC 0603 (1608 Metric) 0.063" L x 0.031" W (1.60mm x 0.80mm)
23 | 4.7pF, 50V | 1 | C389 | CAP0402 | Murata Electronics North America | GRM1555C1H4R7CA01D | Farnell | 2434644 | 4.7pF ±0.25pF 50V C0G, NP0 Ceramic Capacitor -55°C ~ 125°C Surface Mount, MLCC 0402 (1005 Metric) 0.039" L x 0.020" W (1.00mm x 0.50mm)
24 | 1200pF, 50V | 1 | C390 | CAP0402 | Kemet | C0402C122J5GACTU | Digi-Key | 399-7334-1-ND | 1200pF ±5% 50V C0G, NP0 Ceramic Capacitor -55°C ~ 125°C Surface Mount, MLCC 0402 (1005 Metric) 0.039" L x 0.020" W (1.00mm x 0.50mm)
25 | 22nF, 50V | 2 | C391, C413 | CAP0402 | Kemet | C0402C223K5RACTU | Digi-Key | 399-7780-1-ND | 0.022µF ±10% 50V X7R Ceramic Capacitor -55°C ~ 125°C Surface Mount, MLCC 0402 (1005 Metric) 0.039" L x 0.020" W (1.00mm x 0.50mm)
26 | 68pF, 25V | 1 | C411 | CAP0402 | Kemet | CBR04C680F3GAC | Digi-Key | 399-11255-1-ND | 68pF ±1% 25V C0G, NP0 Ceramic Capacitor -55°C ~ 125°C Surface Mount, MLCC 0402 (1005 Metric) 0.039" L x 0.020" W (1.00mm x 0.50mm)
27 | 1500pF, 50V | 1 | C412 | CAP0402 | Samsung Electro-Mechanics America, Inc. | CL05B152KB5NNNC | Digi-Key | 1276-1521-1-ND | 1500pF ±10% 50V X7R Ceramic Capacitor -55°C ~ 125°C Surface Mount, MLCC 0402 (1005 Metric) 0.039" L x 0.020" W (1.00mm x 0.50mm)
28 | Fiducial | 4 | F1, F2, F3, F4 | Fiducial
29 | 600R, 0.27A | 38 | FR1, FR2, FR3, FR4, FR5, FR6, FR7, FR8, FR9, FR10, FR11, FR12, FR13, FR14, FR15, FR16, FR17, FR18, FR19, FR20, FR21, FR22, FR23, FR24, FR25, FR26, FR27, FR28, FR29, FR30, FR31, FR32, FR33, FR34, FR35, FR38, FR39, FR55 | RES0201 | Taiyo Yuden | BK0603TS601-T | Digi-Key | 587-3277-1-ND | FERRITE BEAD 600 OHM 0201 1LN | NF(FR18 FR25)
30 | 600R, 2A | 25 | FR36, FR37, FR40, FR41, FR42, FR43, FR44, FR45, FR46, FR47, FR48, FR49, FR50, FR51, FR52, FR53, FR54, FR56, FR57, FR58, FR59, FR60, FR61, FR62, FR63 | RES0805 | TDK Corporation | MPZ2012S601AT000 | Digi-Key | 445-2206-2-ND | FERRITE BEAD 600 OHM 0805 1LN | NF(FR42 FR43)
31 | LMS7002M | 1 | IC1 | LMS7002M_v2 | Lime Microsystems | LMS7002M | Lime Microsystems | LMS7002M | IC FPRF Transceiver LMS7002M; 261 pin aQFN
32 | 24FC64F | 2 | IC2, IC18 | 24FC512 | Microchip Technology | 24FC64F-I/ST | Digi-Key | 24FC64F-I/ST-ND | IC EEPROM 512KBIT 1MHZ 8TSSOP
33 | 24FC512 | 1 | IC3 | 24FC512 | Microchip Technology | 24FC512-I/ST | Digi-Key | 24FC512-I/ST-ND | IC EEPROM 512KBIT 1MHZ 8TSSOP
34 | SKY13323 | 4 | IC4, IC5, IC6, IC7 | SKY13323-378LF | Skyworks Solutions Inc. | SKY13323-378LF | Digi-Key | 683-1334-1-ND | IC SPDT 100MHZ-3GHZ 6-MLPD
35 | EP4CE40F23C8N | 1 | IC8 | FBGA484_A-240 | Altera | EP4CE40F23C8N | Digi-Key | 544-2811-ND | IC FPGA 328 I/O 484FBGA
36 | TS3A5018PWR | 1 | IC9 | TS3A5018PWR | TEXAS INSTRUMENTS | TS3A5018PW | Newark | 71J8329 | IC SWITCH QUAD SPDT 16TSSOP
37 | M25P16 | 1 | IC10 | M25P40-VMN6TPB_SO8N | Micron Technology Inc. | M25P16-VMN6P | Farnell | 1734973 | IC FLASH 16MBIT 75MHZ 8SO
38 | AS4C64M16D2-25BCN | 2 | IC11, IC12 | AS4C64M16D2 | Alliance Memory, Inc. | AS4C64M16D2-25BCN | Digi-Key | 1450-1158-ND | IC SDRAM 64MX16 1.8V 84-FBGA
39 | CYUSB3014-BZXC | 1 | IC13 | CYP-BZX121 | Cypress Semiconductor Corp | CYUSB3014-BZXC | Digi-Key | 428-3182-ND | EZ-USB(R) FX3: SuperSpeed USB Controller, 512 KB, 60 I/Os, 0 to 70 degC, 121-Pin FBGA (BZX121)
40 | SP3010-04UTG | 1 | IC14 | SP3010-04UTG | Littelfuse Inc | SP3010-04UTG | Digi-Key | F3507TR-ND | TVS DIODE 6VWM 12.3VC UDFN
41 | M25P40 | 1 | IC15 | M25P40-VMN6TPB_SO8N | Micron Technology Inc | M25P40-VMN6TPB | Digi-Key | M25P40-VMN6TPBTR-ND | IC FLASH 4MBIT 75MHZ 8SO
42 | LM75 | 1 | IC16 | HWSON8_LM75 | NXP Semiconductors | LM75BTP,147 | Digi-Key | 568-9815-2-ND | SENSOR TEMPERATURE I2C 8HWSON
43 | MAX7322 | 1 | IC17 | MAX7322ATE_QFN16 | Maxim Integrated | MAX7322ATE+ | Digi-Key | MAX7322ATE+-ND | IC I/O EXPANDER I2C 4B 16TQFN
44 | SC18IS602B | 1 | IC19 | SC18IS602B_TSSOP16 | NXP Semiconductors | SC18IS602BIPW,112 | Digi-Key | 568-4785-5-ND | IC BRIDGE SPI/I2C 16-TSSOP | NF(IC19)
45 | LMK00105 | 1 | IC20 | LMK00105SQ | Texas Instruments | LMK00105SQ/NOPB | Digi-Key | LMK00105SQ/NOPBCT-ND | IC CLK BUFFER 2:5 200MHZ 24WQFN
46 | NC7SV74K8XCT | 1 | IC21 | NC7SV74K8XCT | Fairchild Semiconductor | NC7SV74K8X | Digi-Key | NC7SV74K8XCT-ND | IC D-TYPE POS TRG SNGL US8 | NF(IC21)
47 | AD5601BKSZ-REEL7 | 1 | IC22 | AD5601_SOT23-6 | Analog Devices | AD5601BKSZ-REEL7 | Digi-Key | AD5601BKSZ-REEL7TR-ND | IC DAC 8BIT BUFF V-OUT SC70-6
48 | ADF4002 | 1 | IC23 | ADF4002 | Analog Devices Inc | ADF4002BCPZ-RL7 | Digi-Key | ADF4002BCPZ-RL7CT-ND | IC PLL FREQUENCY SYNTH 20-LFCSP
49 | Si5351C | 1 | IC24 | Si5351C_20QFN | Silicon Labs | SI5351C-B-GM | Digi-Key | 336-2402-ND | IC CLK GENERATOR 200MHZ 20QFN
50 | FPF3042 | 1 | IC25 | FPF3042 | Fairchild Semiconductor | FPF3042UCX | Digi-Key | FPF3042UCXCT-ND | IC OR CTRLR SRC SELECT 16WLCSP
51 | AP7361-FGE | 6 | IC26, IC28, IC30, IC32, IC33, IC34 | AP7361 | Diodes Incorporated | AP7361-FGE-7 | Digi-Key | AP7361-FGE-7DICT-ND | IC REG LDO ADJ 1A 8DFN
52 | ADP2386 | 2 | IC27, IC31 | ADP2386 | Analog Devices Inc. | ADP2386ACPZN-R7 | Digi-Key | ADP2386ACPZN-R7DKR-ND | IC REG BUCK ADJ 6A SYNC 24LFCSP
53 | RT9026 | 1 | IC29 | MSOP10 | Richtek USA Inc. | RT9026GFP | Digi-Key | 1028-1010-1-ND | IC DDR TERMINATION REG 10MSOP
54 | LP38503TS | 1 | IC35 | TO-263-5_v2 | Texas Instruments | LP38503TS-ADJ/NOPB | Digi-Key | LP38503TS-ADJ/NOPB-ND | IC REG LDO ADJ 3A TO263-5
55 | SPX3819R2 | 1 | IC36 | SPX3819R2-L/TR | Exar Corporation | SPX3819R2-L/TR | Digi-Key | 1016-1588-1-ND | Linear Voltage Regulator IC Positive Adjustable 1 Output Adjustable 500mA 8-DFN (2x3)
56 | U.FL/MMCX | 12 | J1, J2, J3, J4, J5, J6, J7, J8, J9, J10, J18, J19 | MMCX_UFL_conn_u | Molex, LLC | 0734120110 | Digi-Key | WM5587CT-ND | CONN UMC RCPT STR 50 OHM SMD
57 | FPGA JTAG | 1 | J11 | SWD_10_pin | Harwin Inc | M50-3600542 | Digi-Key | 952-1389-ND | CONN HDR 1.27MM SMD AU 10POS
58 | FPGA GPIO | 1 | J12 | SWD_10_pin | Harwin Inc | M50-3600542 | Digi-Key | 952-1389-ND | CONN HDR 1.27MM SMD AU 10POS
59 | FAN | 1 | J13 | HDR_1x2 | 3M | 961102-6404-AR | Digi-Key | 3M9447-ND | 2 Positions Header, Unshrouded Connector 0.100" (2.54mm) Through Hole Gold | NF(J13)
60 | FAN | 1 | J14 | HDR_1x2_HALF_PITCH | Sullins Connector Solutions | GRPB021VWVN-RC | Digi-Key | S9014E-02-ND | CONN SHUNT 1.27MM BLUE W/HANDLE
61 | Micro_USB3B | 1 | J15 | microUSB3B_SM_v2 | Amphenol Commercial Products | GSB443T33HR | Digi-Key | GSB443T33HRCT-ND | USB - micro B USB 3.1, Superspeed+ Receptacle Connector 10 Position Surface Mount, Right Angle
62 | FX3 JTAG | 1 | J16 | SWD_10_pin | Harwin Inc | M50-3600542 | Digi-Key | 952-1389-ND | CONN HDR 1.27MM SMD AU 10POS
63 | Jumper | 1 | J17 | HDR_1x2_HALF_PITCH | Sullins Connector Solutions | GRPB021VWVN-RC | Digi-Key | S9014E-02-ND | 2 Positions Header, Unshrouded Connector 0.050" (1.27mm) Through Hole Gold
64 | CONN_PWR_JACK_2.1x5.5mm | 1 | J20 | CONN_PWR_JACK_v4 | CUI Inc. | PJ-031DH | Digi-Key | CP-031DH-ND | CON PWR JCK 1.3 X 4.2MM HIGH CUR
65 | Header 3x1 pin | 1 | J21 | HDR_1x3 | Amphenol FCI | 68000-103HLF | Digi-Key | 609-3461-ND | 3 Positions Header, Unshrouded Connector 0.100" (2.54mm) Through Hole Gold or Gold, GXT | NF(J21)
66 | 1 pcs. | 1 | JMP1 | MECH_JUMPER_HALF_PITCH | Harwin Inc. | M50-2030005 | Digi-Key | 952-1732-ND | CONN SHUNT 1.27MM BLUE W/HANDLE
67 | 1.5uH | 1 | L1 | FDVE1040_TOKO_INDUCTOR | Vishay Dale | IHLP4040DZER1R5M01 | Digi-Key | 541-1301-6-ND | FIXED IND 1.5UH 15A 5.8 MOHM SMD
68 | 1uH | 1 | L2 | FDVE1040_TOKO_INDUCTOR | Vishay Dale | IHLP3232DZER1R0M01 | Digi-Key | 541-1371-6-ND | FIXED IND 1UH 18A 5.78 MOHM SMD
69 | LED_RG_SMD | 4 | LED1, LED2, LED7, LED8 | LED-2x0603 | Avago Technologies US Inc. | HSMF-C165 | Digi-Key | 516-1419-1-ND | LED GREEN/RED DIFFUSED 0603 SMD
70 | LED_RG | 4 | LED3, LED4, LED5, LED6 |  | Visual Communications Company - VCC | 4301F1/5 | Digi-Key | 4301F1/5-ND | LED GRN/RED DIFF 3MM ROUND T/H | NF(LED3 LED4 LED5 LED6)
71 | 2xLED standoff | 2 | LEDS1, LEDS2 | LED_STANDOFF_H-201C | Bivar Inc. | H-201C | Digi-Key | 492-1790-ND | LED HOLDER RA 3MM 2LD NYL BK | NF(LEDS1 LEDS2)
72 | # pcs. | 4 | MECH1, MECH2, MECH3, MECH4 | PCB_standoff | FIX&FASTEN | FIX-MAE-5TV | TME | FIX-MAE-5TV | PCB distance; polyamide; L:5mm; Colour: natural; Øcutout:3mm
73 | 100uH | 4 | MN1, MN2, MN29, MN30 | RES0805 | TDK Corporation | MLF2012C101KT000 | Digi-Key | 445-1071-1-ND | FIXED IND 100UH 2MA 3.1 OHM SMD
74 | 47nH | 4 | MN3, MN4, MN31, MN32 | RES0402 | COILCRAFT | 0402HP-47NXJLU | Farnell | 2285856 | INDUCTOR, RF, 47NH, 5%, 2.4GHZ, SMD; Product Range:0402HP Series; Inductance:47nH; Inductance Tolerance:± 5%; High Frequency Inductor Case:0402 [1005 Metric]; Self Resonant Frequency Min:2.4GHz; DC Resistance Max:0.58ohm; DC Current Rating:420mA
75 | 0.5pF | 6 | MN6, MN15, MN22, MN34, MN43, MN50 | CAP0402 | Yageo | CC0402CRNPO9BNR50 | Digi-Key | 311-1001-1-ND | 0.50pF ±0.25pF 50V C0G, NP0 Ceramic Capacitor -55°C ~ 125°C Surface Mount, MLCC 0402 (1005 Metric) 0.039" L x 0.020" W (1.00mm x 0.50mm) | NF(MN6 MN22 MN34 MN50)
76 | 2pF | 6 | MN7, MN21, MN24, MN35, MN49, MN52 | CAP0402 | AVX | 04025U2R0BAT2A | Farnell | 2332536 | 2pF ±0.1pF 50V C0G, NP0 Ceramic Capacitor -55°C ~ 125°C Surface Mount, MLCC 0402 (1005 Metric) 0.039" L x 0.020" W (1.00mm x 0.50mm)
77 | 0uH (0R) | 4 | MN9, MN10, MN37, MN38 | RES0805 | BOURNS | CR0805-J/-000ELF | Farnell | 2008388 | RES SMD 0.0 OHM JUMPER 1/8W 0805
78 | 8.2nH, 5% | 6 | MN11, MN12, MN18, MN39, MN40, MN46 | RES0402 | COILCRAFT | 0402HP-8N2XJLU | Farnell | 2285826 | INDUCTOR, RF, 8.2NH, 5%, 5.4GHZ, SMD; Product Range:0402HP Series; Inductance:8.2nH; Inductance Tolerance:± 5%; High Frequency Inductor Case:0402 [1005 Metric]; Self Resonant Frequency Min:5.4GHz; DC Resistance Max:0.065ohm; DC Current Rating:1.5A
79 | 0.8pF | 6 | MN13, MN16, MN27, MN41, MN44, MN55 | CAP0402 | Murata Electronics North America | GRM1555C1HR80BA01D | Digi-Key | 490-6269-1-ND | 0.80pF ±0.1pF 50V C0G, NP0 Ceramic Capacitor -55°C ~ 125°C Surface Mount, MLCC 0402 (1005 Metric) 0.039" L x 0.020" W (1.00mm x 0.50mm)
80 | 1pF | 4 | MN14, MN23, MN42, MN51 | CAP0402 | TDK Corporation | C1005C0G1H010B050BA | Digi-Key | 445-4854-6-ND | 1pF ±0.1pF 50V C0G, NP0 Ceramic Capacitor -55°C ~ 125°C Surface Mount, MLCC 0402 (1005 Metric) 0.039" L x 0.020" W (1.00mm x 0.50mm) | NF(MN14 MN42)
81 | 510pF | 4 | MN17, MN20, MN45, MN48 | CAP0402 | Murata Electronics North America | GRM1555C1H511JA01D | Digi-Key | 490-3237-1-ND | 510pF ±5% 50V C0G, NP0 Ceramic Capacitor -55°C ~ 125°C Surface Mount, MLCC 0402 (1005 Metric) 0.039" L x 0.020" W (1.00mm x 0.50mm)
82 | 1.2pF | 2 | MN19, MN47 | CAP0402 | Murata Electronics North America | GRM1555C1H1R2CA01D | Digi-Key | 490-5927-1-ND | 1.2pF ±0.25pF 50V C0G, NP0 Ceramic Capacitor -55°C ~ 125°C Surface Mount, MLCC 0402 (1005 Metric) 0.039" L x 0.020" W (1.00mm x 0.50mm)
83 | 10nH, 5% | 2 | MN26, MN54 | RES0402 | COILCRAFT | 0402HP-10NXJLU | Farnell | 2285830 | INDUCTOR, RF, 10NH, 5%, 4.7GHZ, SMD; Product Range:0402HP Series; Inductance:10nH; Inductance Tolerance:± 5%; High Frequency Inductor Case:0402 [1005 Metric]; Self Resonant Frequency Min:4.7GHz; DC Resistance Max:0.11ohm; DC Current Rating:1.3A
84 | 10k, 1% | 38 | R1, R2, R3, R4, R5, R10, R11, R48, R49, R50, R55, R58, R66, R67, R103, R104, R105, R115, R116, R117, R119, R125, R127, R128, R129, R130, R132, R133, R160, R161, R180, R186, R187, R195, R200, R205, R207, R211 | RES0402 | Yageo | RC0402FR-0710KL | Digi-Key | 311-10.0KLRTR-ND | RES SMD 10K OHM 1% 1/16W 0402 | NF(R49 R67 R116 R119)
85 | 49.9R, 1% | 16 | R6, R7, R8, R9, R46, R47, R140, R152, R159, R163, R164, R165, RA3, RA4, RA7, RA8 | RES0402 | Samsung Electro-Mechanics America, Inc. | RC1005F49R9CS | Digi-Key | 1276-3469-6-ND | RES SMD 49.9 OHM 1% 1/16W 0402
86 | 2k2, 1% | 2 | R12, R13 | RES0402 | Stackpole Electronics Inc | RMCF0402FT2K20 | Digi-Key | RMCF0402FT2K20CT-ND | RES SMD 2.2K OHM 1% 1/16W 0402
87 | 100R, 1% | 15 | R14, R16, R17, R18, R20, R21, R76, R79, R80, R82, R85, R86, R168, R169, R170 | RES0402 | Stackpole Electronics Inc. | RMCF0402FT100R | Digi-Key | RMCF0402FT100RDKR-ND | RES SMD 100 OHM 1% 1/16W 0402
88 | 1k, 1% | 13 | R15, R19, R62, R131, R134, R135, R154, R174, R179, R190, R193, R198, R203 | RES0402 | Stackpole Electronics Inc | RMCF0402FT1K00 | Digi-Key | RMCF0402FT1K00TR-ND | RES SMD 1K OHM 1% 1/16W 0402 | NF(R15 R19)
89 | 0R | 69 | R22, R23, R24, R25, R26, R27, R28, R29, R30, R42, R43, R44, R45, R51, R52, R53, R54, R56, R57, R59, R60, R61, R63, R64, R65, R72, R74, R92, R106, R107, R108, R110, R111, R112, R113, R120, R122, R124, R136, R137, R138, R139, R141, R142, R143, R144, R145, R146, R147, R148, R149, R150, R151, R155, R157, R158, R166, R167, R173, R176, R177, R178, R188, R191, R192, R202, R204, R208, R212 | RES0402 | Yageo | RC0402JR-070RL | Digi-Key | 311-0.0JRTR-ND | RES SMD 0.0OHM JUMPER 1/16W 0402 | NF(R52 R53 R57 R60 R63 R65 R74 R92 R111 R120 R122 R124 R141 R143 R144 R145 R146 R147 R148 R149 R151 R155 R166 R167 R177 R212)
90 | 0R | 7 | R31, R32, R34, R35, R36, R37, R38 | RES0201 | Rohm Semiconductor | MCR006YRTJ000 | Digi-Key | RHM0.0CCCT-ND | RES SMD 0.0OHM JUMPER 1/20W 0201
91 | 10R | 4 | R33, R39, R40, R41 | RES0201 | Panasonic Electronic Components | ERJ-1GEF10R0C | Digi-Key | P10.0ABCT-ND | RES SMD 10 OHM 1% 1/20W 0201
92 | 22R | 3 | R68, R98, R99 | RES0402 | Yageo | RC0402FR-0722RL | Digi-Key | 311-22.0LRTR-ND | RES SMD 22 OHM 1% 1/16W 0402
93 | 100K | 3 | R69, R114, R118 | RES0402 | Panasonic Electronic Components | ERJ-2GEJ104X | Digi-Key | P100KJCT-ND | RES SMD 100K OHM 5% 1/10W 0402
94 | 4K7 | 6 | R70, R71, R73, R121, R123, R126 | RES0402 | Stackpole Electronics Inc. | RMCF0402JT4K70 | Digi-Key | RMCF0402JT4K70TR-ND | RES SMD 4.7K OHM 5% 1/16W 0402
95 | 8x56R | 6 | R75, R77, R78, R81, R83, R84 | EXB2HV | PANASONIC ELECTRONIC COMPONENTS | EXB2HV560JV | Farnell | 2060070 | RES ARRAY 8 RES 56 OHM 1506
96 | 22R | 11 | R87, R88, R89, R90, R91, R94, R96, R97, R100, R101, R102 | ChipResistorArray | Yageo | YC124-JR-0722RL | Digi-Key | YC124J-22TR-ND | RES ARRAY 4 RES 22 OHM 0804
97 | 6.04K, 1% | 1 | R93 | RES0402 | Rohm Semiconductor | MCR01MRTF6041 | Digi-Key | RHM6.04KCDTR-ND | RES SMD 6.04K OHM 1% 1/16W 0402
98 | 200R, 1% | 1 | R95 | RES0402 | Stackpole Electronics Inc | RMCF0402FT200R | Digi-Key | RMCF0402FT200RDKR-ND | RES SMD 200 OHM 1% 1/16W 0402
99 | 2.21k, 1% | 2 | R109, R184 | RES0402 | Stackpole Electronics Inc. | RMCF0402FT2K21 | Digi-Key | RMCF0402FT2K21CT-ND | RES SMD 2.21K OHM 1% 1/16W 0402
100 | 10R, 5% | 1 | R153 | RES0402 | Yageo | RC0402JR-0710RL | Digi-Key | 311-10JRTR-ND | RES SMD 10 OHM 5% 1/16W 0402
101 | 470R, 0.5% | 2 | R156, R175 | RES0402 | Panasonic Electronic Components | ERA-2AED471X | Digi-Key | P470DETR-ND | RES SMD 470 OHM 0.5% 1/16W 0402
102 | 330R, 5% | 1 | R162 | RES0402 | Yageo | RC0402JR-07330RL | Digi-Key | 311-330JRTR-ND | RES SMD 330 OHM 5% 1/16W 0402
103 | 249R, 1% | 1 | R171 | RES0402 | Stackpole Electronics Inc | RMCF0402FT249R | Digi-Key | RMCF0402FT249RCT-ND | RES SMD 249 OHM 1% 1/16W 0402
104 | 0R | 1 | R172 | RES0805 | Vishay Dale | CRCW08050000Z0EA | Digi-Key | 541-0.0ATR-ND | RES SMD 0.0 OHM JUMPER 1/8W 0805 | NF(R172)
105 | 44.2k, 1% | 3 | R181, R185, R196 | RES0402 | Panasonic Electronic Components | ERJ-2RKF4422X | Digi-Key | P44.2KLCT-ND | RES SMD 44.2K OHM 1% 1/10W 0402 | NF(R181 R196)
106 | 806R, 1% | 3 | R182, R197, R206 | RES0402 | Stackpole Electronics Inc | RMCF0402FT806R | Digi-Key | RMCF0402FT806RCT-ND | RES SMD 806 OHM 1% 1/16W 0402
107 | 100k, 5% | 1 | R183 | RES0402 | Panasonic Electronic Components | ERJ-2GEJ104X | Digi-Key | P100KJTR-ND | RES SMD 100K OHM 5% 1/10W 0402
108 | 750R, 1% | 1 | R189 | RES0402 | Yageo | RC0402FR-07750RL | Digi-Key | 311-750LRCT-ND | RES SMD 750 OHM 1% 1/16W 0402
109 | 560R, 1% | 3 | R194, RA1, RA5 | RES0402 | Vishay Dale | CRCW0402560RFKED | Digi-Key | 541-560LCT-ND | RES SMD 560 OHM 1% 1/16W 0402
110 | 124k, 1% | 1 | R199 | RES0402 | Panasonic Electronic Components | ERJ-2RKF1243X | Digi-Key | P124KLCT-ND | RES SMD 124K OHM 1% 1/10W 0402
111 | 66.5k, 1% | 1 | R201 | RES0402 | Panasonic Electronic Components | ERJ-2RKF6652X | Digi-Key | P66.5KLDKR-ND | RES SMD 66.5K OHM 1% 1/10W 0402
112 | 39k, 1% | 1 | R209 | RES0402 | Yageo | RC0402FR-0739KL | Digi-Key | 311-39.0KLRCT-ND | RES SMD 39K OHM 1% 1/16W 0402
113 | 23.2k, 1% | 1 | R210 | RES0402 | Yageo | RC0402FR-0723K2L | Digi-Key | YAG3066CT-ND | RES SMD 23.2K OHM 1% 1/16W 0402
114 | 2.49k, 1% | 2 | RA2, RA6 | RES0402 | Yageo | RC0402FR-072K49L | Digi-Key | 311-2.49KLRDKR-ND | RES SMD 2.49K OHM 1% 1/16W 0402
115 | Switch, tactile | 1 | SW1 | SW_tactile | Omron Electronics Inc-EMC Div | B3U-1000P | Digi-Key | SW1020TR-ND | SWITCH TACTILE SPST-NO 0.05A 12V
116 | TC1-1-13MA+ | 6 | T1, T3, T5, T6, T8, T10 | TC1-1-13MA+_v2 | Mini-Circuits | TC1-1-13MA+ | Minicircuits | TC1-1-13MA+ | RF balun, TC1-1-13MA+
117 | TCM1-63AX+ | 4 | T2, T4, T7, T9 | TCM1-63AX+_v2 | Mini-circuits | TCM1-63AX+ | Minicircuits | TCM1-63AX+ | RF balun, TCM1-63AX+
118 | SK36A | 1 | VD1 | DIODE_SMB | Micro Commercial Co | SK36A-LTP | Digi-Key | SK36A-LTPMSCT-ND | DIODE SCHOTTKY 60V 3A DO214AC
119 | RF MOSFET | 6 | VT1, VT2, VT3, VT4, VT5, VT6 | BF1105R_SOT143R4 | NXP Semiconductors | BF1105R,215 | Digi-Key | 568-12530-6-ND | RF MOSFET Transistors Trans MOSFET N-CH 7V 0.03A 4pin(3+Tab)
120 | NDS331N | 1 | VT7 | SOT23-3 | Fairchild Semiconductor | NDS331N | Digi-Key | NDS331NCT-ND | MOSFET N-CH 20V 1.3A SSOT3
121 | 30.72 MHz | 1 | XO1 | RAKON_RPT7050A | Rakon | E6245LF | Rakon | E6245LF | TCXO 30.72MHz, E6245LF | NF(XO1)
122 | TCXO 30.72MHz | 1 | XO2 | RAKON_TXCO | Rakon | E5280LF | Rakon | E5280LF | TCXO 30.72MHz, E5280LF
123 | 19.2MHz | 1 | XT1 | CRYSTAL_4-LCC_v2 | CTS-Frequency Controls | 405C35B19M20000 | Digi-Key | CTX648CT-ND | 19.2MHz ±30ppm Crystal 13pF 60 Ohm -20°C ~ 70°C Surface Mount 4-SMD, No Lead (DFN, LCC)
124 | 25MHz | 1 | XT2 | CRYSTAL_4-LCC | ABRACON | ABM8-25.000MHZ-B2-T | Newark | 13J1767 | 25MHz ±20ppm Crystal 18pF 50 Ohm -20°C ~ 70°C Surface Mount 4-SMD, No Lead (DFN, LCC)
 |  |  |  |  |  |  |  |  |  | Total NF element number: 60
 |  |  |  |  |  |  |  |  |  | All NF elements in one row:
 |  |  |  |  |  |  |  |  |  | NF(C341 C324 C325 C142 FR18 FR25 FR42 FR43 J13 J21 LED3 LED4 LED5 LED6 LEDS1 LEDS2 MN6 MN22 MN34 MN50 MN14 MN42 R49 R67 R116 R119 R15 R19 R52 R53 R57 R60 R63 R65 R74 R92 R111 R120 R122 R124 R141 R143 R144 R145 R146 R147 R148 R149 R151 R155 R166 R167 R177 R212 R172 R181 R196 XO1 IC19 IC21)
 |  |  |  |  |  |  |  |  |  | *NOTE: NF(R1 R2) means that elements R1 and R2 are unpopulated (NF)

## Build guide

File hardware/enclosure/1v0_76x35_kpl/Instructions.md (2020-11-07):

## Assembly instructions for LimeSDR KIT
#### 1. Checklist:
In the beginning check that you have everything available and ready
##### Materials:
You need to get separately:
- LimeSDR board
- 12x SMA U.FL pigtails (5cm/2inch in this manual)

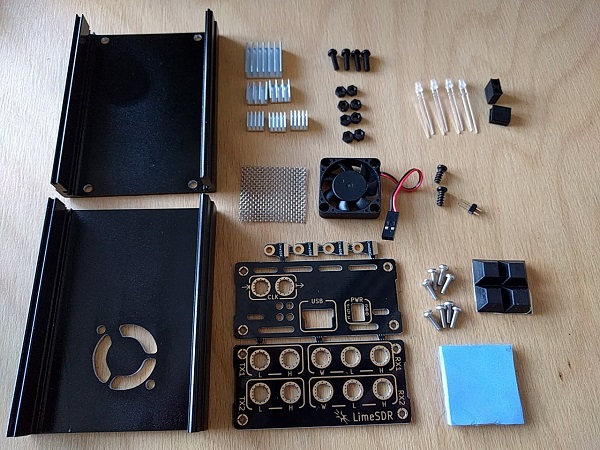
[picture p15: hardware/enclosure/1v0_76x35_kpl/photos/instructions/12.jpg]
Materials


##### Checklist for KIT:
- alu shell bottom (4 holes)
- alu shell top (fan cutout, 2 holes)
- 4 rubber pads
- 4 plastic screws
- 8 plastic nuts
- fan 30x30 5v
- mesh
- pinheader
- heatpad (1pcs, cut later into more pcs)
- heatsinks (1x + 2x + 3x)
- PCB panel (front, rear)
- 8 panel screws, torx
- 2 LED holders with leds installed

##### Tools:
- soldering iron kit
- basic screwdriver set ([link]( https://www.ebay.com/sch/i.html?_nkw=31+in+1+screwdriver))
- sandpaper OR diamond files
- wrench size 8 (8 mm) for SMA pigtails

___
#### 2. Prepare LimeSDR board:
##### for FAN:
Populate/solder 0.1" pinheader on the board

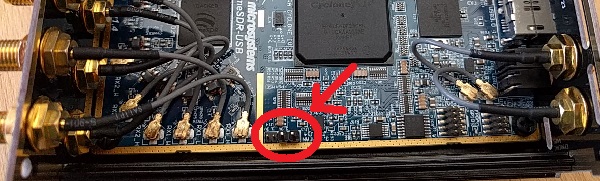
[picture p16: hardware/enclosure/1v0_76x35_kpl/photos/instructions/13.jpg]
Pinheader

##### for LEDs:
1. solder LEDs on the board. (Previously some more steps were needed to assemble leds into holder)
___
#### 3. Mount fan on top shell:
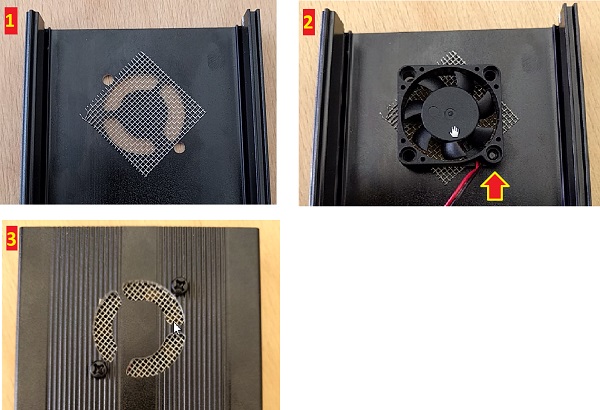
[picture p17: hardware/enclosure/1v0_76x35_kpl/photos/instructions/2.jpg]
Fan


1. position steel mesh
2. place fan as on photo (exhaust fan, cable downward facing), partially screw one metal screw, align steel mesh to cover the cutout
3. mount 2nd screw and tighten both
___
#### 4. Mount "standoffs":
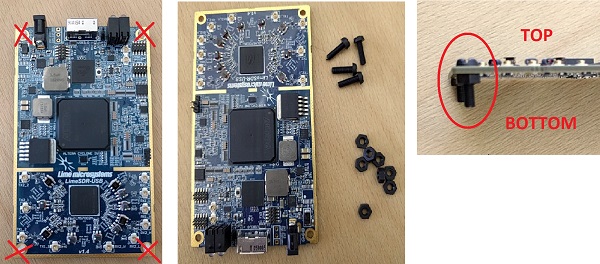
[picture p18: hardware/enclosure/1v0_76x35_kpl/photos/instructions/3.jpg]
Standoffs


remove stock standoffs, put plastic screws from top and fix with plastic nut
___
#### 5. Cut and attach heatpad:
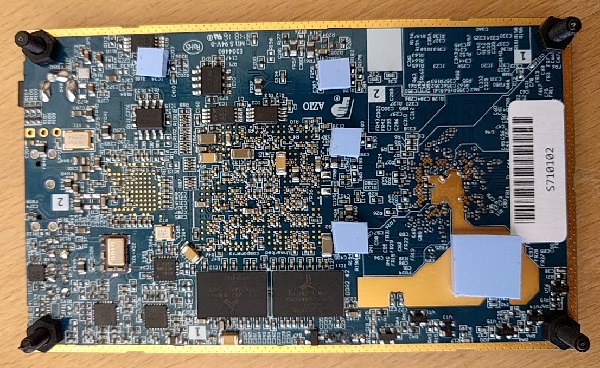
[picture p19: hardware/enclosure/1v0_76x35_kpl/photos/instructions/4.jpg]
Heatpad


1. take scissors and cut 4 smaller pieces, mount them on voltage regul. (AP7361-FGE, IC28, IC30, IC33, IC34)
2. put remaining part on bare metal
___
#### 6. Screw on bottom shell:
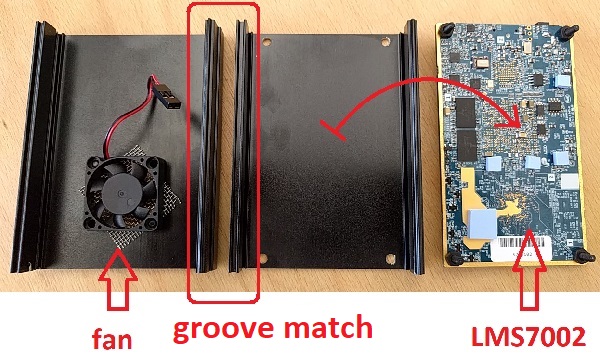
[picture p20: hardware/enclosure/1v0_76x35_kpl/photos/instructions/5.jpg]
Bottom_shell


##### !!! WARNING: Orientation of both shells is very important when mounting, see shell grooves
1. place all three components as on photo
1.a fan on bottom
1.b grooves that fit together
1.c RF IC on bottom
2. turn bottom shell over and screw remaining 4 plastic nuts
___
#### 7. Attach rubber feet:
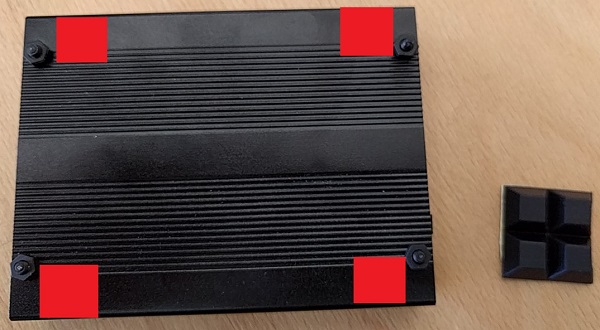
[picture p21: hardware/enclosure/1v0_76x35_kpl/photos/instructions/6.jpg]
Rubber_feet


I attached them as red squares on photo
___
#### 8. Prepare front and rear panel:
Break apart and use sandpaper or diamond files to smooth places where tabs were previously

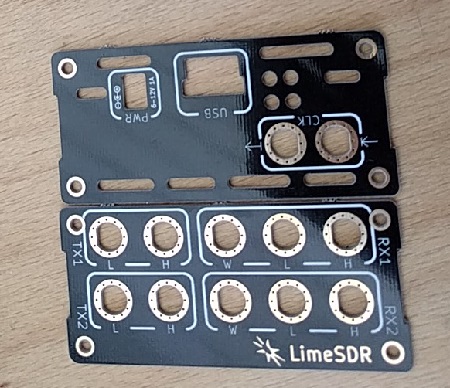
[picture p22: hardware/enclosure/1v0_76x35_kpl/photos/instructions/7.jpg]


(optional) Use black permanent marker and color around the PCB rim

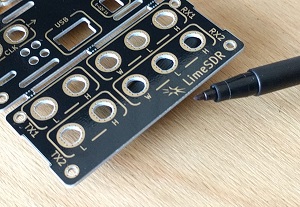
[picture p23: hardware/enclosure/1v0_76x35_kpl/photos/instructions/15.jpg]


Use 8mm wrench to tighten SMA connectors firmly.

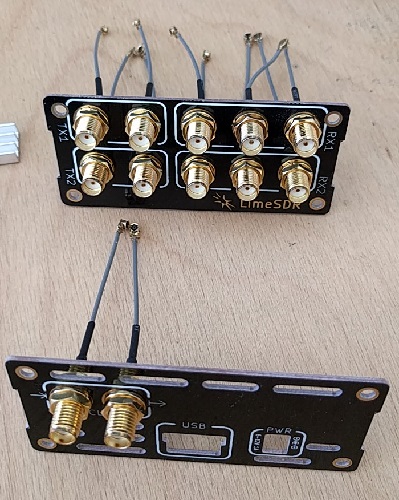
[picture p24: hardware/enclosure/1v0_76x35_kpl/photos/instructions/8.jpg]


___
#### 9. Mount SMA pigtails:
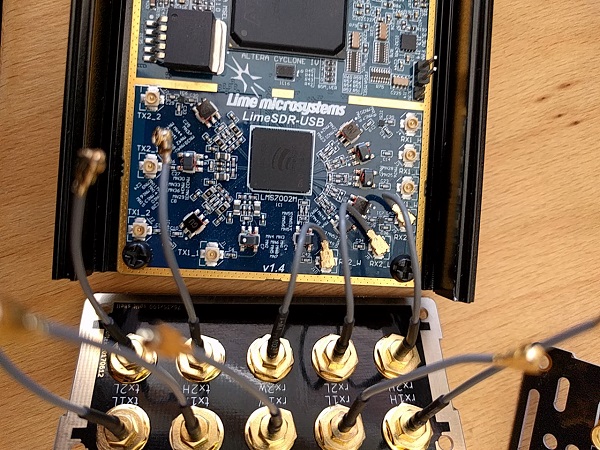
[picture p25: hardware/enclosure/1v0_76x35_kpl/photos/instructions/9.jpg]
Pigtails


Attach pigtails as marked on panels
RX in v1.4 is marked as on front panel PCB
TX1_1 = tx1L, TX1_2 = tx1H  
TX2_1 = tx2L, TX2_2 = tx2H 
After attaching pigtails you are ready to slowly mount both panels. Rearrange pigtails as needed. Use torx screws for mounting.

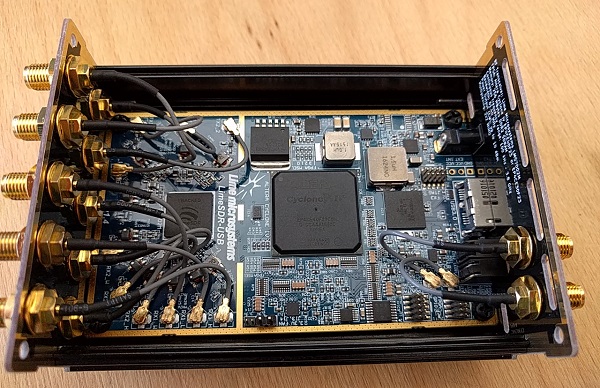
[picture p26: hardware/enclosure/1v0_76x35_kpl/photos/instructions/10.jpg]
Pigtails_2

___
#### 10. Attach heatsinks and fan:
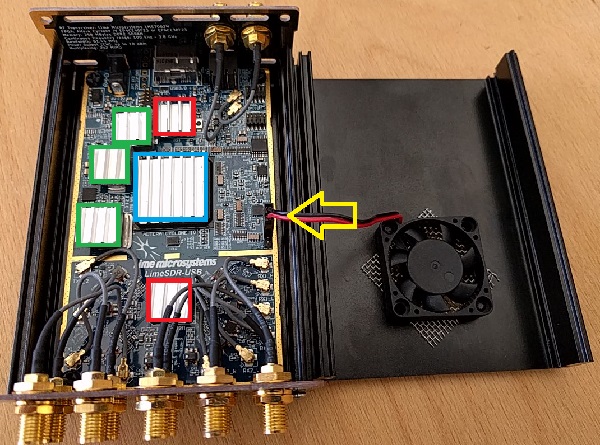
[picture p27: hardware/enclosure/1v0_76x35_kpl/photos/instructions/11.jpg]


All heatsinks are rotated as airflow. | green - small | red - medium | blue - big | Fan connector as photo (red wire toward front panel)

Check FAN operation by manually changing state ON/OFF: https://github.com/luftek/LimeSDR-USB/issues/19

Continue using your LimeSDR! ;)
___
Please place an issue OR send eBay message if something should be improved. Thank you!

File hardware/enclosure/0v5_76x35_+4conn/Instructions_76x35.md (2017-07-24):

# Instruction for assembly 76x35

In the beginning your desk should look like this (check BOM for suggested parts and tools)

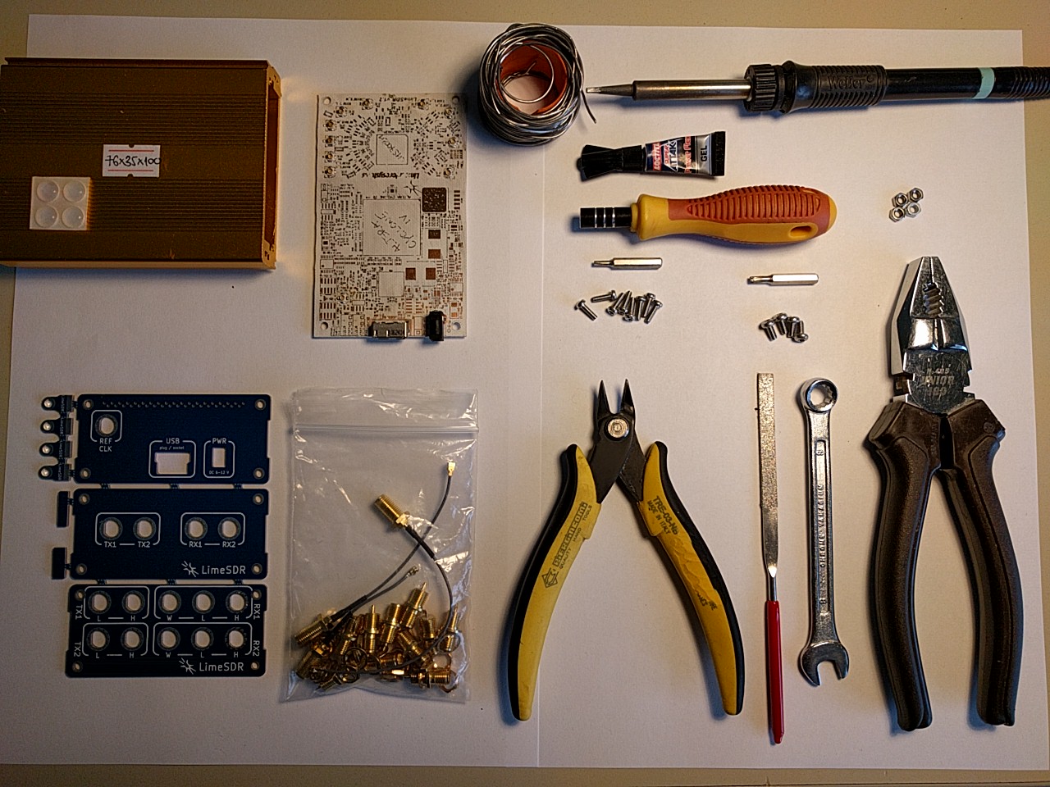
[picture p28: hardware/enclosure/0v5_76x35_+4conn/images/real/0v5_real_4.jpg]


Design 76x35

Design 76x35

Firstly break apart the panel with wire cutters and file remaining pieces

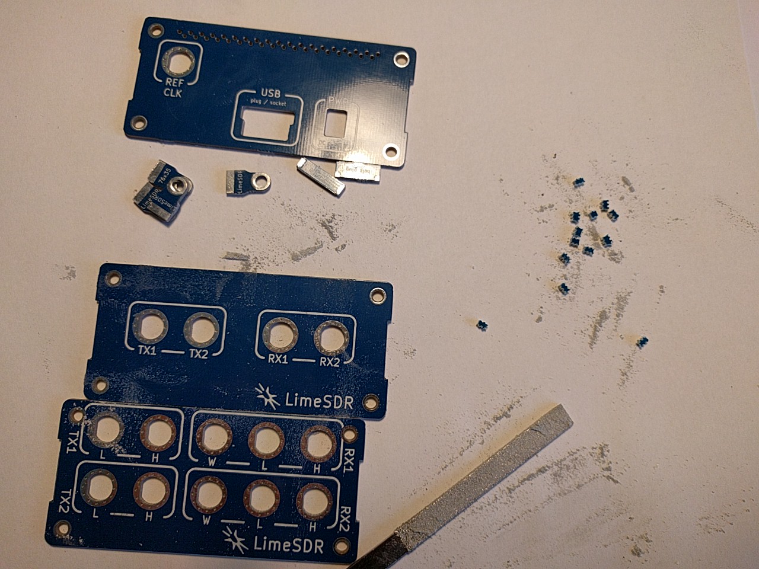
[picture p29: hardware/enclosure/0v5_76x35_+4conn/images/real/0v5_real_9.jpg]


Decide which hole plug u need to use and solder it into place or use fast glue. I went fo micro usb

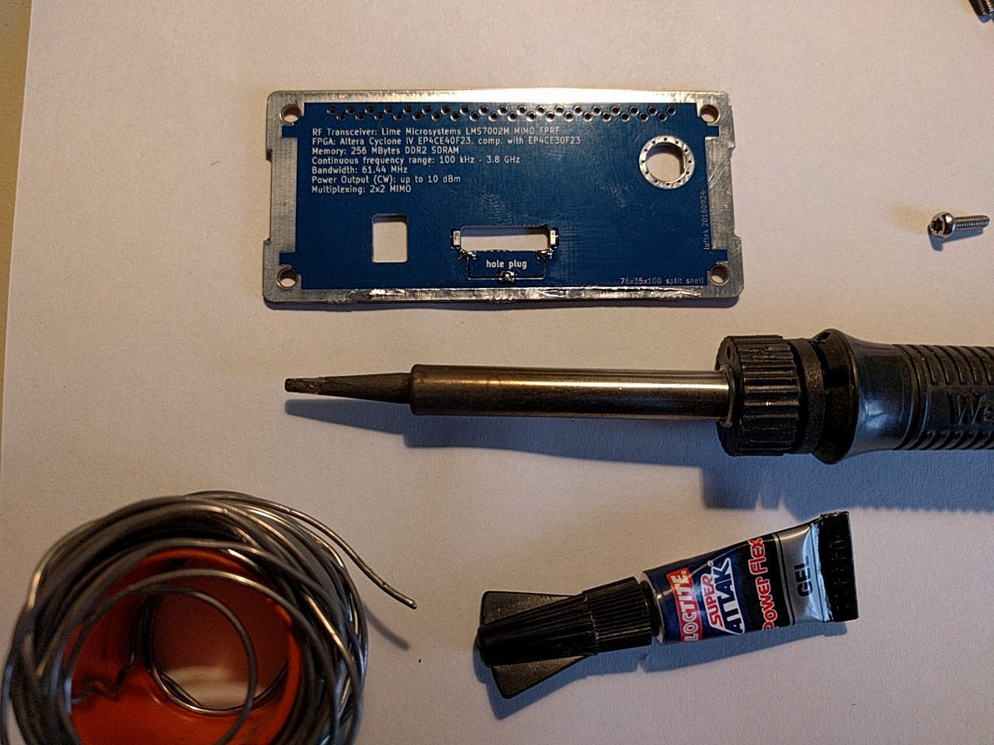
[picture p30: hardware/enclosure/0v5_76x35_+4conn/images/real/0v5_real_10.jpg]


Install rear panel

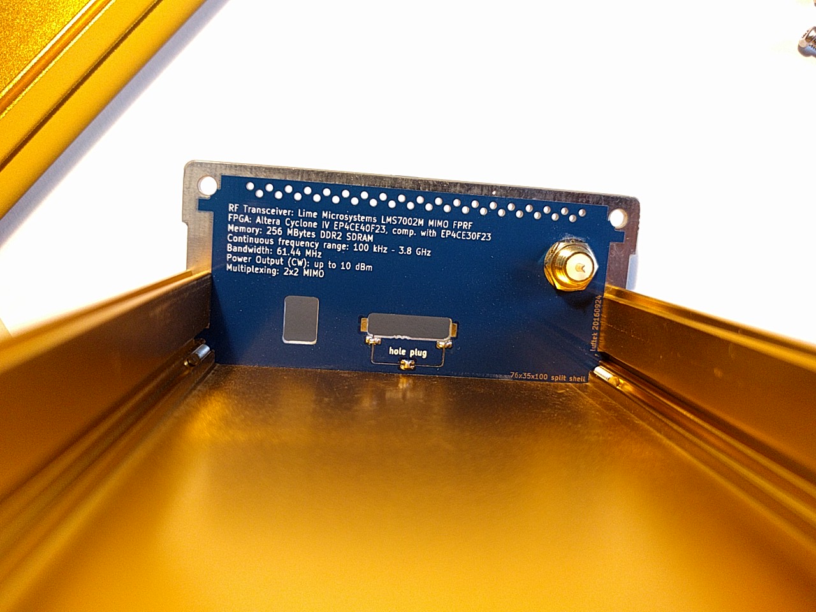
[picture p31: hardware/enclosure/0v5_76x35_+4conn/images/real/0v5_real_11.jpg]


Install the tabs. Tabs are on top of Lime, also put screw from top side so nut is secured on the bottom

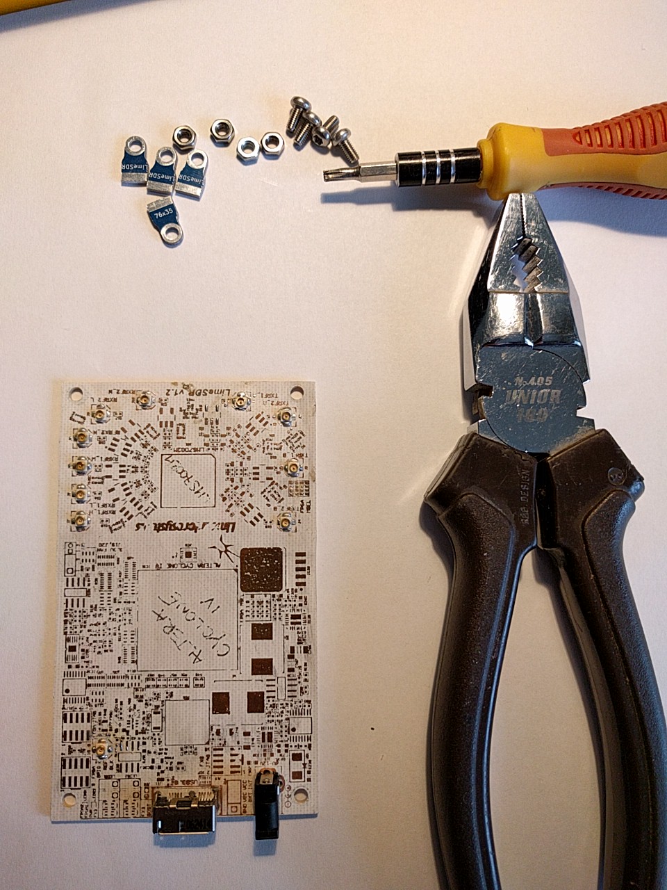
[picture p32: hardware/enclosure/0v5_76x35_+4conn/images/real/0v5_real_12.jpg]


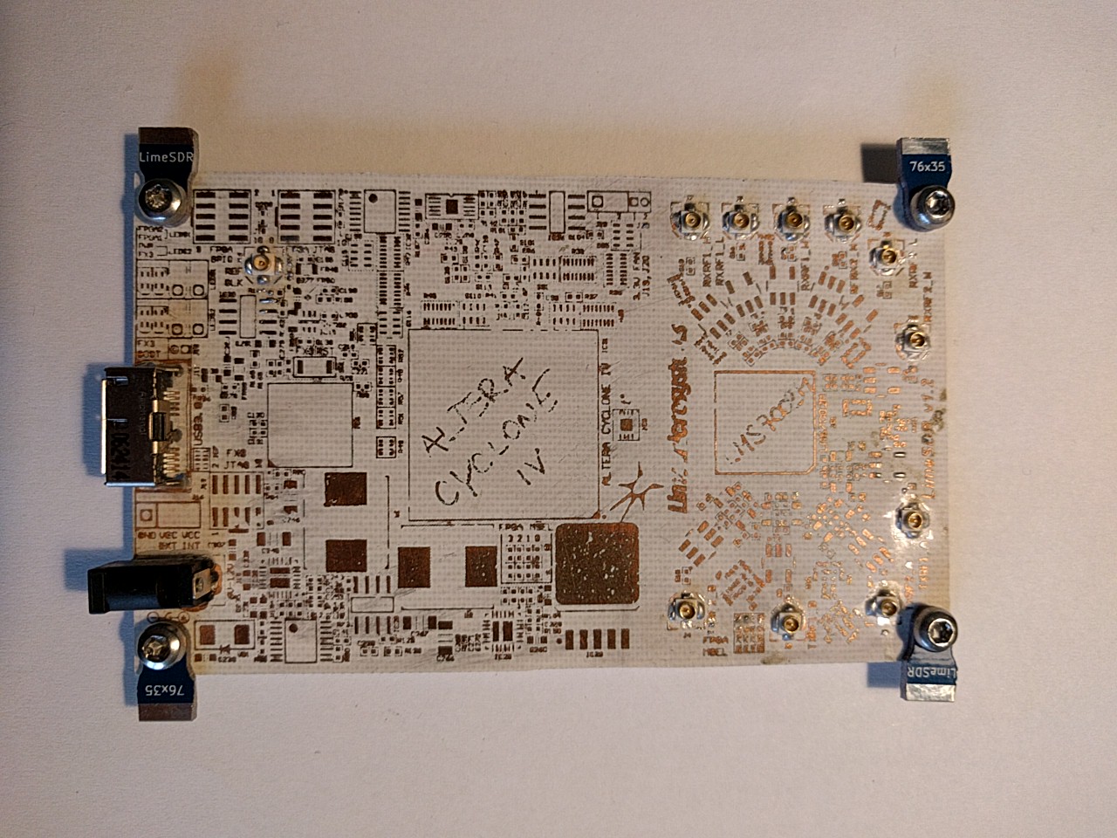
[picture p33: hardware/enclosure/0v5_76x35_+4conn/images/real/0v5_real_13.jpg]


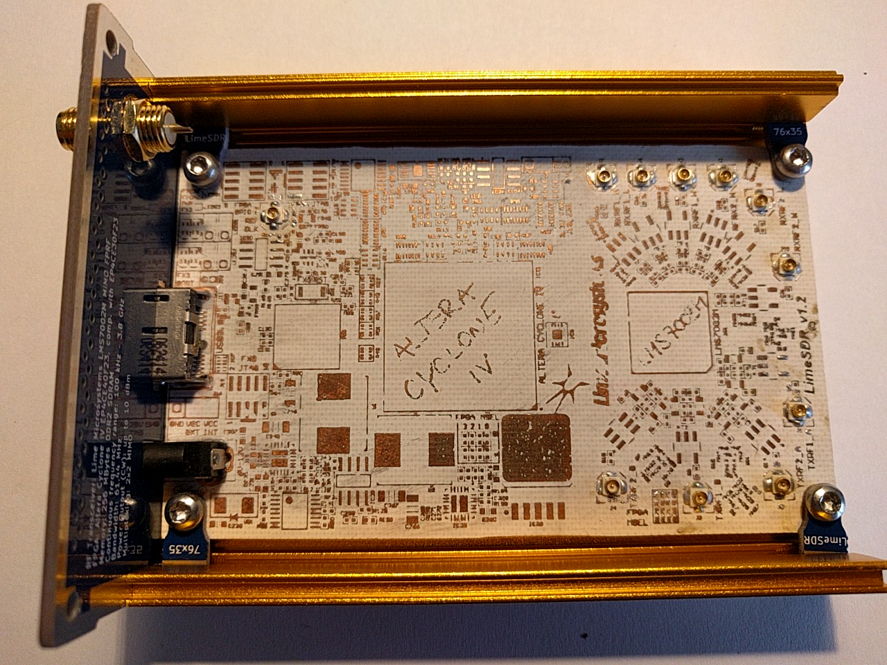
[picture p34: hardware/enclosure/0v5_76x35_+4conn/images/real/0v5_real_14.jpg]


Pick which front panel suits you and connect cables according datasheet/markings on the LimeSDR board and front panel OR your decision which to route out

Design 76x35

Design 76x35

Screw top part of split enclosure.
Use antislip rubber pads on bottom and maybe on the side

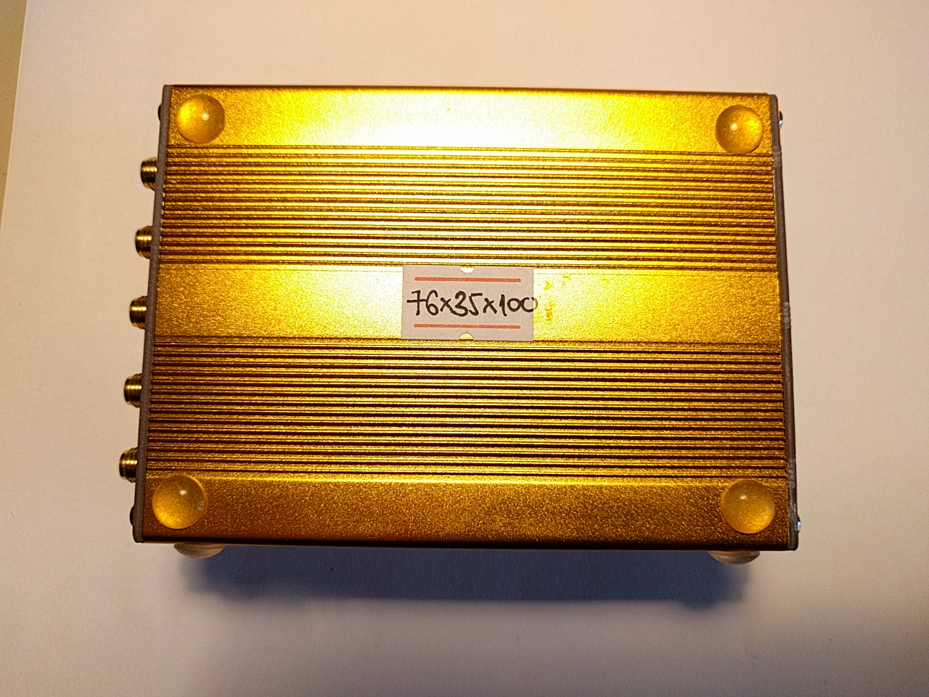
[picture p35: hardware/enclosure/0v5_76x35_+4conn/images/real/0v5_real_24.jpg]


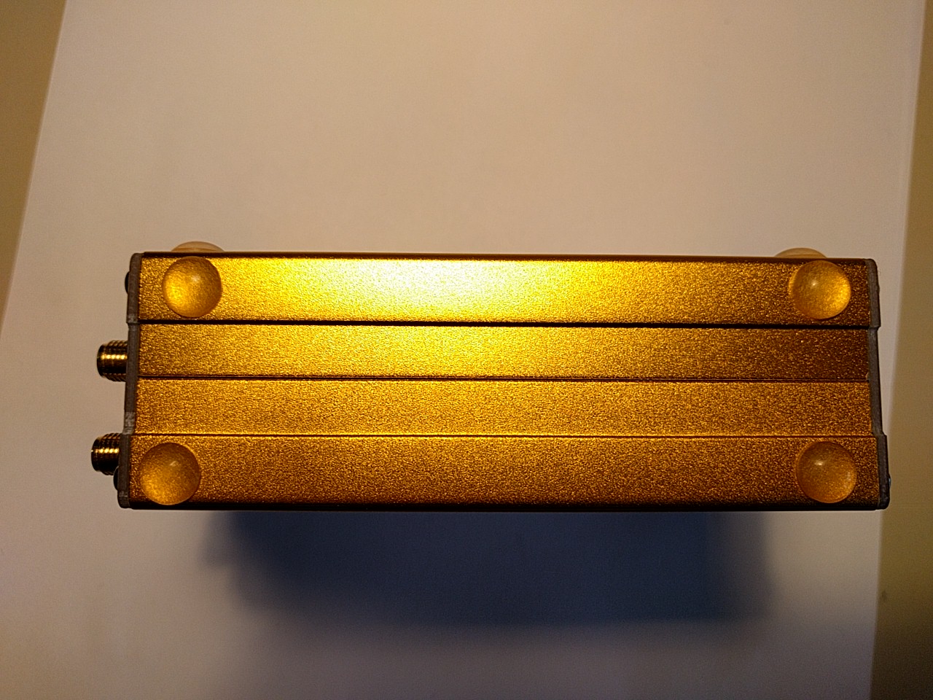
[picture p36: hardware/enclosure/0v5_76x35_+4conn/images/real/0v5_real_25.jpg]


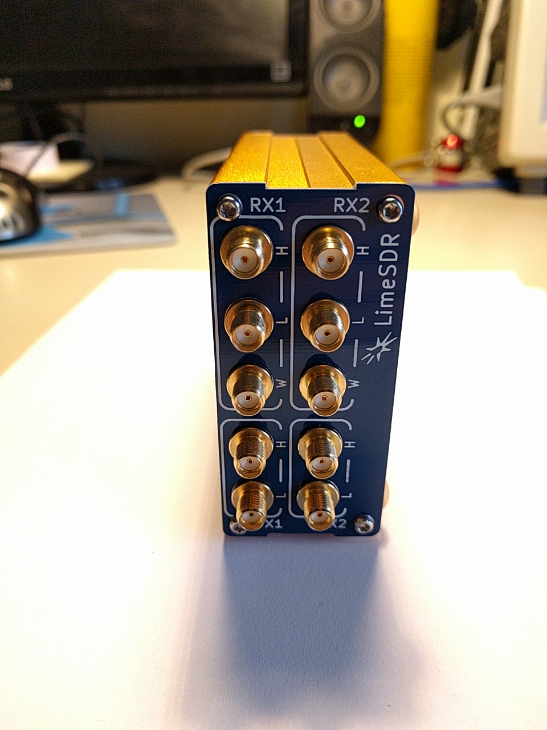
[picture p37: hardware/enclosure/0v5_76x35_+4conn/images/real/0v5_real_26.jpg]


Please place an issue if something should be improved. Thank you!

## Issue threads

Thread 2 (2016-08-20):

Naming order RX, front panel

luftek, 2016-08-20:
"The only thing I can see that I would have liked to be different was the order of the RX connectors.  On the LimeSDR board they are L, H, W and the panel they are marked L,W,H.  Not a big problem but maybe nice if they were in the same order."

John g0orx/n6lyt

m3us, 2016-08-30:
As long as it is labelled ,I don't think it is a big issue.

luftek, 2016-09-11:
They seem to be named W, L, H ?
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

Closed 2016-09-24.

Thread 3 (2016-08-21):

Version with just 4 connectors on front panel

luftek, 2016-08-21:
A lot of folks will probably connect and use just 4 U.Fl connections to dev board.
Just a change to the placement of SMA connectors and silkscreen is needed.

luftek, 2016-09-02:
added 4 connector front panel with latest commit
![Sample Enclosure 76x35 4 connectors] (https://github.com/luftek/LimeSDR-USB/raw/master/hardware/plug/1v2/Enclosure/0v4_Alu_Sample_76x35/_images/2016-09-02%2019_20_11-76x35_front_4conn.png)

Closed 2016-09-02.

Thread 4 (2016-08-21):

is DC socket populated on the board?

luftek, 2016-08-21:
It this is not the case:
- I need to make a hole plug for DC plug also OR
- put suitable 3.5 mm DC socket in BOM.xlsx

m3us, 2016-08-29:
Hey Luftek,I think it will be populated since its mentioned in the BOM here

https://github.com/myriadrf/LimeSDR-USB/blob/master/hardware/plug/1v2/Project%20Outputs%20for%20LimeSDR_1v2/BOM/LimeSDR_1v2_BOMr1.xls

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

luftek, 2016-08-29:
Yes, probably true. Just saw some prototype boards without. I will still add a jack in BOM.xlsx

Closed 2016-08-29.

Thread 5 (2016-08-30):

Questions regarding BOM for new enclosure

m3us, 2016-08-30:
I just went through the BOM you put up and purchased most of the items except the set of 8*m2.5 screws

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

Don't cases come with those screws already
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

Also what do the rubber pads do?

luftek, 2016-08-30:
Correct, phillips head screws are included with enclosure.
Put rubber pads on bottom so enclosure won't slide on your table. :)

Closed 2016-08-30.

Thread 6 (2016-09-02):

Panels screws are too long

luftek, 2016-09-02:
M2.5 - 12 mm screws meant for front panel are too long!
See photo, when screwed all the way in

**8 mm are better suited**

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

Closed 2016-09-02.

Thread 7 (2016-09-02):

Heat dissipation

luftek, 2016-09-02:
Things could get hot, do we need to add cooling holes on the panels?
Maybe transfer heat to the enclosure?

m3us, 2016-09-07:
LimeSDR draws around 3W to 4W MAX.But I guess vents would'nt hurt.
Vent holes on back panel would do.

luftek, 2016-09-24:
thank you @m3us !
added holes on Rear panel

Closed 2016-09-24.

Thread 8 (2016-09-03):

Text on which layer? Silkscreen or Soldermask

luftek, 2016-09-03:
I am not sure which is best option for text.
Silkscreen could have manufacturing restrictions while soldermask is usually accurate.

I have this process capability card in my hand: https://www.itead.cc/bare-pcb-pcb-process-capability-demonstrate-card.html

And logo and text on right lower part is used a Soldermask is visible very cleanly:

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

Also using ENIG pops even more:
https://www.tindie.com/products/NsN/pcb-color-sample-set/

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

m3us, 2016-09-07:
Displaying text on PCB using solder mask and ENIG coating would look nice.Especially if it is black color PCB.

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

m3us, 2016-09-11:
I just got KiCAD and I'm working on moving the items from silkscreen to solder mask layer.

luftek, 2016-09-11:
It takes a simple find and replace in text editor and you are done ;)

m3us, 2016-09-11:
Lol.You are right
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

Either way what do you think about the colour scheme?I have seen this in real life before and it looks nice

luftek, 2016-09-11:
I think I will stay with blue and hasl for this batch. Black is black :) and wants to hide, but sure looks polished.

m3us, 2016-09-11:
Okay :(
I suggested it because the aluminium enclosure is black.

luftek, 2016-09-11:
Is blue, gold not your color of liking :)

m3us, 2016-09-11:
Blue PCB with gold aluminum enclosure like what you have looks nice..
Blue PCB with black aluminum enclosure not so much,hence why I suggest black PCB for black enclosure.

xmikos, 2016-09-23:
If I can weight in, I would also much more prefer black PCB :-) Most people will have black enclosure and black PCB looks better with it.

luftek, 2016-09-24:
close this issue, Text stays on Silkscreen for now.
Panel colour is defined at production order

Closed 2016-09-24.

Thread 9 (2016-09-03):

Clearance on bottom side because of TXCO module

luftek, 2016-09-03:
Clearance on bottom side because of TXCO module with overall height 2mm
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

luftek, 2016-09-11:
Clearance between the board and bottom part of enclosure is max. 2.8 mm and min. 2.4 mm when tabs are on low part of groove
**STILL:**
It is important to place M3 nut on bottom side, as on the photo, nut is about 2.4 high and will add additional support to board if board is pressed down
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

Additional explanation:
LimeSDR board thickness is 1.6 mm
Panel board is 1.6 mm
Groove on enclosure is 2 mm
travel up/down is 0.4 mm You can reduce it by placing a spot of solder on the bottom of tabs

luftek, 2016-09-11:
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

Closed 2016-09-11.

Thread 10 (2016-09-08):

Hole_plug soldering pad place

luftek, 2016-09-08:
Lower hole_plug piece needs different soldering pads (mounting pads) because in this configuration solder interferes with main board

Closed 2016-09-10.

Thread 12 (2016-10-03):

Status LEDs

luftek, 2016-10-03:
Where should Status LEDs be accessible?
How much are they needed?

They (Lime Microsystems) suggest we use:
4x LED GRN/RED DIFF 3MM ROUND T/H  (Digi-Key    4301F1/5-ND)
2x LED_STANDOFF_H-201C                     (Digi-Key    492-1790-ND)
the board was designed for (BOM)

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

luftek, 2016-10-03:
[http://eu.mouser.com/ProductDetail/Bivar/H-201C/?qs=sGAEpiMZZMtU66%252bVMtdfbiIxtAK9LgjB](http://eu.mouser.com/ProductDetail/Bivar/H-201C/?qs=sGAEpiMZZMtU66%252bVMtdfbiIxtAK9LgjB )

luftek, 2016-10-04:
http://vcclite.com/product/cbi-2pos-bi-level-led-4/

luftek, 2016-11-03:
CONSIDERING LIGHT PIPES
light fiber + 4 small holes on rear and front panel (1.2 mm)

Have not find anything DIY yet.
Concern is mounting on LEDs in semi permanent fashion.

Light fiber in diameter of 1mm (blue outline) would cover both dies on this small 0603 leds
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

I can currently only try 0.35 mm wide light fiber used in:
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

luftek, 2017-07-24:
Commit: dc9700f for design files 1v0 predicts already made holes for LEDs

Closed 2017-07-24.

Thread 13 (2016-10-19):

Enclosure of lower height/profile for 4 conn version

zigastegu, 2016-10-19:
Nice! I bought one. Do you have any plans for releasing another case with lower height? Thanks. - freebil

luftek, 2016-10-31:
maybe 100*71*25mm http://www.everestcase.com/upload/2014071515071066.pdf5 (datasheet is not complete)
http://www.everestcase.com/en/productsd.php?pid=11662 which can be probably same as http://www.ebay.com/itm//2016284554915

luftek, 2016-11-05:
Candidates according to filter
60 < width <80
20 < height < 30
legth = 100

http://www.everestcase.com/en/productsd.php?pid=1166
http://www.everestcase.com/en/productsd.php?pid=877
http://www.everestcase.com/en/productsd.php?pid=802
http://www.everestcase.com/en/productsd.php?pid=901
http://www.everestcase.com/en/productsd.php?pid=101
http://www.everestcase.com/en/productsd.php?pid=10142

luftek, 2016-11-18:
I found datasheet with most dimension marked on Taobao (a lot of edited ones).
This seems to be closes to original:

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

https://img.alicdn.com/imgextra/i1/116848420/TB2VrbAbXXXXXasXpXXXXXXXXXX_!!116848420.jpg

luftek, 2016-11-18:
Sample of
Rear_panel_71x25 in production with some other boards

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

luftek, 2016-11-25:
shipped from Fab

luftek, 2016-12-10:
Received the sample. Unfortunatelly, did not receive enclosure yet
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

I have too much of this back plates now. :/ :)

luftek, 2016-12-29:
- bit crammed, where is place for LEDs?
- width and height OK, but not best (height needs additional 1mm, width 0.5mm)
- 4 mount holes need more clearance
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

should i then divide into 2 panels, one for 4 front connectors and one for 10 front connectors?
should i pursue whole enclosure kit assembly with cutouts made in aluminum? MOQ 100pcs :/

zigastegu, 2020-03-23:
This development was discontinued. 🤔🤦

Closed 2020-03-23.

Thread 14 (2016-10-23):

Changed BOM and placement of parts

luftek, 2016-10-23:
Does recent change of BOM and placement affect "connector" position? With connector position I mean: both USB versions, DC socket, LEDs, u.fl conn
Thank you for support!

luftek, 2016-10-24:
See more about this question on: [http://github.com/myriadrf/LimeSDR-USB/issues/8#](http://github.com/myriadrf/LimeSDR-USB/issues/8#)
According first information, change does not affect enclosure design.
Additional REF_CLK_OUT will be assigned as enhacement in new issue.

Closed 2016-10-24.

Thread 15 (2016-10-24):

Suggestions for new board enclosure

Dovydas-R, 2016-10-24:
Great job but I have some suggestions:
1. Add additional SMA hole for REF_CLK_OUT
2. Rename existing REF_CLK to REF_CLK_IN
3. Add DC connector polarity information
4. Current case version hides board LEDs.
   It is possible to connect external LEDs to LimeSDR-USB board so you can put LEDs on case panel and connect them using pinheader connector to LimeSDR-USB board.
5. Possible thermal issues due to poor thermal conductivity of board edges and aluminum enclosure.
6. To improve thermal conditions add ventilation holes and prepare mounting for fan.

luftek, 2016-10-24:
1. agree
2. agree
3. agree, was just thinking about that, usually it is positive polarity, but not always the case (Gameboy DMG has negative)
4. #12  I am not sure to place them on rear panel, I would rather place them on front
5. and 6. are currently out of my reach (didn't have LimeSDR yet, waiting on campaign delivery) some holes are added on rear panel #7

luftek, 2016-10-30:
So, I have made changes for first 4 suggestions:
1., 2. done, 2nd CLK io added
3. added symbol for positive polarity, Walter Lain's lib [http://smisioto.no-ip.org/elettronica/kicad/kicad-en.htm](http://smisioto.no-ip.org/elettronica/kicad/kicad-en.htm)
4. added 3d models from Dialight, BUT still not sure if LED holes should be predrilled.

Need to check influence of parallel SMD and TH LEDs. Desoldering of SMD LEDs is unwanted.

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

luftek, 2016-11-01:
https://github.com/myriadrf/LimeSDR-USB/issues/8

luftek, 2016-11-04:
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

Dovydas-R, 2016-11-07:
Looks OK

luftek, 2016-11-07:
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

Dovydas-R, 2016-11-26:
Several weeks ago I received enclosure from Ziga (Luftek). Thanks!

Precisely made front and back PCB panels looks great.
LimeSDR board fits perfectly.

Some thermal tests we performed:
- Board withot enclosure and without fan reached 71 °C temperature after 1 hour of operating.
- Same board placed in Luftet case reched 76 °C after 1 hour of operating.

So thermal condistions for board in not perfect.
I also really missed any LED indicators on panel.
If all earlier mentioned sugestions will be implemented, this enclosure could be good alternative for other LimeSDR enclosures.

I'm attaching some pictures.

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

vince48, 2016-11-26:
thanks for sharing

Vincent

On Sat, Nov 26, 2016 at 12:36 PM, Dovydas Rusinskas <
notifications@github.com> wrote:

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

luftek, 2016-11-26:
Thank you on photos. Sry did not include cables

- How did this test look like?
- Any conclusion wether we need to siphone this heat away?
- What are temp spec. of RF chip, thermal shutdown at?

Maybe we can write answers here, in comments below.

Dovydas-R, 2016-11-28:
Board RF RX1 channel was receiving on 80 MSPs for 1 hour. Temperature was measured using onboard temperature sensor. This is not maximum board load.

In my opinion the normal board board operating temperature  is up to 60°C.

I think best way to reduce temperature inside would be use of FAN, mounted on the top. This needs to make holes in the case. It would be very nice to have fan guard (grill). Holes and guard can be made by one machining operation in aluminum case. Board has connector for FAN (3,3V) and is temperature controlled. Of course, the enclosure must have additional holes to ensure proper air circulation (inlet and outlet, outside -> inside -> outside). Fan  example: http://www.digikey.com/product-detail/en/sunon-fans/MC30060V2-000U-A99/259-1572-ND/2757810

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

Another not so effective solution could be heat transfer from board edges to aluminum case. This needs good thermal contact between board and case.

luftek, 2016-11-30:
QFN 11.5×11.5 mm package

Dovydas-R, 2016-12-01:
Not only transceiver chip (LMS7002) produces heat when operating, but also FPGA, RAMs, LDOs etc.
Rod between enclosure and one or more chips will be complicated and not so effective solution.

FAN on the top of the board was tested and it is simple and effective solution.

luftek, 2016-12-04:
Can you share test from setup where you used fan on top of the board?
Was board "free" or in any enclosure?

I will check for aluminum/brass heatsinks, maybe RPi are compatible

luftek, 2016-12-04:
https://www.ettus.com/content/images/B205mini-i_heat_sink_2_2.jpg

luftek, 2016-12-29:
Thermal Camera in Customs, hopefully arrives next week.
Then need to wait for LimeSDR to arrive for actual thermal testing 👍

luftek, 2017-07-12:
http://www.ebay.com/itm/-/122582037877?

luftek, 2017-07-24:
Fan, heatsinks, heatpad used in version 1v0
Commit: dc9700f
Kit sold on eBay: http://www.ebay.com/itm/-/122582037877

Closed 2017-07-24.

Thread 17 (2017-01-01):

Active cooling - FAN

luftek, 2017-01-01:
Some preparation, if we really need active cooling:

Supply for fan is 3.3 V.
Fan is controlled with N-mosfet.

Control voltage must be over about 1.5V for mosfet to turn ON and pass more than enough current
Control is done by FPGA (pin E4)  or LM75 open drain output (0R resistor not placed)
LM75 has an  open drain output LM75 OS which is pulled-up by an external 10k R
OS Polaritiy can be set to active high or active low. If directly connected to mosfet setting must be active high.

Retail available fans of size 30 and 40 mm come with conn pitch 2.54 so a 2-pin male header must be additionally soldered
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

Most retail fans come for voltages 5, 12 and 24V so 5V fan with 3.3V supply must be checked
Example fans 5V in 1pcs QTY with shipping
30x30x7: http://www.ebay.com/itm/301966472303  1.5$
40x40x7: http://www.ebay.com/itm/400965990547   2.5$
40x40x10: http://www.ebay.com/itm/222325450566 1.5$
40x40x10: http://www.ebay.com/itm/252478255390 1.5$

Clearance for fan and heatsink in 4 io enclosure will matter

Datasheets:
https://www.fairchildsemi.com/datasheets/ND/NDS331N.pdf
http://datasheets.maximintegrated.com/en/ds/LM75.pdf

Shematics from: https://github.com/myriadrf/LimeSDR-USB/blob/master/hardware/plug/1v4/Project%20Outputs%20for%20LimeSDR-USB_1v4_LMS031pad/LimeSDR-USB_1v4_schematic_r4.PDF

lleoha, 2017-03-07:
👍
Active cooling would be great, as my Lime is overheating unfortunately.
@luftek Did you consider using small 17x17x5  3.3V DC fan like this one:
http://www.digikey.com/en/product-highlight/c/copal/f17fa-03mc-mini-brushless-dc-fan
or even smaller one (15x15x4.5 but this one is 5V  DC):
http://www.ebay.com/itm/15x15mm-Super-Small-Brushless-DC-Fan-Ultra-Tiny-Miniature-Mini-Micro-Smallest-/181152651845

I would prefer to have it as small as possible to fit it on the PCB panel instead of metal case itself (I think is would be easier for me - I don't have tools to make good looking holes in metal case) and (if needed) put some radiators on chips.

Let me know what you think.. If there is anything I can help you with let me know.
Thanks!

luftek, 2017-03-07:
I didn't know, so small fans exist :) Friend milled aluminum cutouts for me and are at postal office. i go pick them up tomorrow. will update this comment.

Currently I know of 2 temperatures that can be read.
1. dedicated chip - LM75, LimeSuite supports it
2. internal LMS temperature, LimeSuite does has this functionality but does not work correctly in my version (maybe need update)

How do you do temperature testing, reading?

lleoha, 2017-03-07:
I was using pyrometer and the chip temperature was ca. ~80*C

luftek, 2017-07-12:
some progress with KIT, which is avaiable on eBay. Instructions and BOM.csv follows shortly
http://www.ebay.com/itm/-/122582037877?

luftek, 2017-07-24:
Fan used in version 1v0
Commit: dc9700f
Kit sold on eBay: http://www.ebay.com/itm/-/122582037877

Closed 2017-07-24.

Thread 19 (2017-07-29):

FAN Manual Control

luftek, 2017-07-29:
How to check if board drives FAN output correctly?
1. Wait for the temperature to raise above 55°C for FAN to turn on, and below 45°C again to turn OFF
2. Manual option?

Fan is driven with FAN_CTRL signal from FPGA. FPGA internally has NIOS2 cpu instance that sets temperature module LM75 to hysteresis 45 and 55°C with output signal which is rerouted through FPGA input through internal MUX to FAN_CTRL (E4) output

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

**Hardcoded test:**
- periphcfg.vhd reserves memory:
```
mem(12)	<= "000000000000000x"; --  0 free, PERIPH_OUTPUT_OVRD_0
mem(13)	<= "000000000000000x"; --  0 free, PERIPH_OUTPUT_VAL_0
```
default values are both 0 and further uses LSB bits for driving FAN_CTRL (see photo above)
changing LSB of mem(12) changes source and mem(13) is manual signal

I have compiled 2 versions based on https://github.com/myriadrf/LimeSDR-USB_GW/commit/0f021ca1b6faf9a09b5736b25f60ee6e562a5822:
and used LimeUtil.exe to flash them on FPGA
[test_FPGA_Fan.zip](https://github.com/luftek/LimeSDR-USB/files/1185036/test_FPGA_Fan.zip)

**WIP:**
I think changing this memory addresses is possible over SPI as LimeSuite GUI implements features for 16bit spi board writing also "cpu" in FPGA handles writing for GPIO
Q:
Main question what is the offset address? Do need to change any other register before writing this address? FPGA SPI Slave Select?

Hopefully digging through implementation of GUI FPGA GPIO will give us answers

luftek, 2017-07-29:
I was so close :)
offsets are:
0xCC - 0 = auto, 1= manual
0xCD - 0 = off, 1 = on

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

Hyseas, 2017-08-04:
I think I am missing something. I went to Board SPI, Write, entered the hex values as shown above, issued a CMD Write command, received Status: Write success.  However, Read, entered the hex values as shown above, issued a CMD Read command and the Read success never varied from Hex: 0x0000.  I could not get values to change or the fan to turn on.  Can you please elaborate on the process to test the fan manually?

luftek, 2017-08-04:
0xCC - 0 = auto, 1= manual
0xCD - 0 = off, 1 = on

Hyseas, 2017-08-04:
Thank you for your response. I think I tried that but may still be doing it wrong. Let me provide some additional information.

I have the LimeSDR-USB v1.4 with updated firmware. I'm using Lime Suite GUI v17.02.2-PothosSDR-2017.05.16-vc1. I have gone to Options>ConnectionSettings and selected USB 3.0 (LimeSDR-USB) [USB] 9061C02CA0B20. The log shows the device connected.

I then select Options>SPI>Board SPI (section)>Write>Address (Hex): and enter "0xCC". Then go to Write>Value (Hex): and enter "01". I then enter "CDM Write", which returns "Status: Write success".

I then select Board SPI (section)>Read>Address (Hex): and enter "0xCC" and enter "CDM Read". It returns >Read Value (Hex): 0x0000 and Status: Read Success. (see below)
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

I also tried the format shown (FFFF) and used Value (Hex): 0001. Still the same result. I really would like to test the fan, so any guidance or direction is greatly appreciated. Thank you.

Closed 2017-07-29.

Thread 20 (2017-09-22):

LimeSDR Mini Edition

Manouchehri, 2017-09-22:
Bit early, but thought I'd comment that it'd be awesome to see a similar (and smaller) enclosure for the LimeSDR Mini when it comes out.

luftek, 2017-10-03:
https://github.com/myriadrf/LimeSDR-Mini design files are available
Forked: https://github.com/luftek/LimeSDR-Mini

Manouchehri, 2017-10-04:
Nice, thanks!

zigastegu, 2020-03-23:
I can just add that plastic enclosures for Mini Editions exist and seems to do a decent job protecting the board.
**I really like:**
Yet another LimeSDR Mini Case by ornotermes
https://www.thingiverse.com/thing:3120637

According to licence I could also made it available though **eBay store:**
https://www.ebay.com/itm/123395291206

Closed 2017-10-03.

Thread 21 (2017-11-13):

LED improvements

ynezz, 2017-11-13:
Hi,

thanks a lot for a great case and a this project! Just a small nitpicks:

1. I had to drill bigger holes(+1mm in diameter) for the 4 LEDs, otherwise I wouldn't be able to put it all together with the screws. Bottom of the LEDs are wider by about 1mm in diameter so the 3mm hole isn't big enough so the front panel doesn't align with the aluminium case.

2. I miss the description of the LEDs on the panel. Maybe you can add the some info about the LEDs in the free space above USB and PWR connectors? Or just move the clock IN/OUT connectors more to the left (above USB/PWR connectors) and add description of the LEDs above the LEDs?

luftek, 2017-11-13:
Thank you for taking the time to comment here!

1. Leds don't fit in plastic holders without modification. Please check instructions for assembly? Maybe something is not well described. I could not source "original" ones. No need to drill holes on PCB/rear panel.

2. Hm... Yes I guess something could be done for predefined ones

Any visual explanation for both comments would be very helpful to me.

ynezz, 2017-11-13:
>  Please check instructions for assembly?

I've found this GitHub repository after I've finished the assembly, here it's clear, that you've modified LEDs so they fit in the holes. I've simply completed the assembly from the photos on your eBay listing as I couldn't find any mention about this assembly instructions, maybe I've just missed it :-)

>  Maybe something is not well described

It's OK, maybe just put small paper with URL to the assembly instructions to the package?

> Yes I guess something could be done for predefined ones

Just some description of the LEDs, so it's clear which one is `LED1`, `LED4`, `FX3/USB` and `Power`. Currently there's no text describing the purpose of the LEDs and one has to [open image with description](https://wiki.myriadrf.org/images/c/cb/LimeSDR-USB-LEDs.jpg) to find out which one is `LED1` for example.

I understand, that `LED1` and `LED4` are user configurable LEDs, but this could be fixed with either custom front panel or custom sticker once needed.

luftek, 2017-11-13:
https://github.com/luftek/LimeSDR-USB/blob/master/hardware/enclosure/1v0_76x35_kpl/Instructions.md

luftek, 2017-11-13:
WIP: this comment is work in progress

Rear panel view:
R top:
- VCC3P3, green means power is applied and rail 3v3 works
R bottom:
- FX3, green idle
- FX3, red means data flow

L top:
/
L bottom:
/ have no clue, should check SW implementation

Closed 2020-03-23.

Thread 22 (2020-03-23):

Improve assembly documentation

zigastegu, 2020-03-23:
**Base:**
https://github.com/zigastegu/LimeSDR-USB/blob/master/hardware/enclosure/1v0_76x35_kpl/Instructions.md

**Possible subtasks:**
- review latest state of components
- new photos (panel was updated long long time ago 🤦)
- remove steps (led stack assembly)

**Video:**
Think about assembly video. Video can be even more descriptive than photo manual.

zigastegu, 2020-11-07:
- [ ] remove steps (led stack assembly)

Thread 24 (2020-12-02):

Type suggestion for 12x SMA U.FL pigtails

aentinger, 2020-12-02:
Hi @zigastegu :wave:

Great kit, I'm currently working on assembling it. However, I need a bit of help with those **12x SMA U.FL pigtails (5cm/2inch in this manual)** connectors. I've looked around a bit on various pages (Farnell Element 14, Mouser) and have not been able to find such short cables. As I'd like to avoid a bad purchase would you please be so kind as to share the type identification of the pigtails used in your assembly?

All the best, Alex

zigastegu, 2020-12-05:
Hi. In eBay listing I suggest this ones:
https://www.ebay.com/itm/171598054838?var=470590537181

aentinger, 2020-12-07:
Thank you :rocket:

Closed 2020-12-07.

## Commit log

2016-05-11 Initial idea commit sample enclosure
    Initial idea commit:
    Parts for this sample developement ordered:
    - sample alu enclosure
    - 3.1 micro USB connector
    - dc jack
    - U.FL connectors 11pcs
    - U.FL to SMA cables different lengths
    - DIP and bar LED
    - reverse mount LEDs for status
2016-05-11 add image enclosure
2016-05-11 Front Panel PCB - 10xSMA
    [Front_Panel.kicad_pcb, Front_Panel.sch]
2016-05-11 Low, High, Wide - TX
    fix
    [Front_Panel.kicad_pcb]
2016-05-11 fix
    fuc*
    [Front_Panel.kicad_pcb]
2016-05-29 0v2 in dev
    - mockup LimeSDR made
    - partially completed 0v1 enclosure (front panel)
    - ordered new wider enclosures
    [1.27_to_2.54_adapter.kicad_pcb, 1.27_to_2.54_adapter.sch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]
2016-06-20 Update on 0v2, enclosure 97x40x100
    [Back_Panel - Copy.kicad_pcb, Front_Panel - Copy.kicad_pcb, Front_Panel.kicad_pcb]
2016-06-21 Holding tabs added
    LimeSDR campaing is succesful.
    [Board_supports.kicad_pcb, Front_Panel.sch]
2016-06-27 added holes for USB and DC jack
    also exported Gerber files and tried do panelize. Something is wrong.
    Inconsistent use of layers in KiCad. Will revise this in 0v3
    Status update:
    Searching for people who own LimeSDR already
    [1.27_to_2.54_adapter.kicad_pcb, 1.27_to_2.54_adapter.sch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]
2016-07-11 panel sent to PCB fab
    [1.27_to_2.54_adapter.kicad_pcb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]
2016-08-01 PCB received, sample sent to LimeSDR owner
    Will check if any of China/Honk Kong
2016-08-01 BOM exported to .xls and added link, prices
    [BOM.xls]
2016-08-15 init for new 76x35
    - BOM.xls -> BOM.xlsx
    - Instructions for assembly
    [1.27_to_2.54_adapter.kicad_pcb, BOM.xls, BOM_76x35.xlsx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]
2016-08-18 BOM 76x35 fix
    M2.5 screw, not M3 for front and rear panel
    [BOM_76x35.xlsx]
2016-08-21 76x35 sent to fab house
    [BOM_76x35.xlsx, Back_Panel - Copy.kicad_pcb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]
2016-08-29 quick change: readme, bom
    [BOM_76x35.xlsx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]
2016-08-29 q fix
    [BOM_76x35.xlsx]
2016-08-30 BOM comments and screws are (optional)
    [BOM_76x35.xlsx]
2016-09-02 Fixes bug #6
    Optional screws length modified and hex key size also fixed
    [BOM_76x35.xlsx]
2016-09-02 4 conn version
    - 4 connector version,
    - added sidecuts to better fit enclosure
    [BOM_76x35.xlsx, Front_Panel_76x35.kicad_pcb, Front_Panel_76x35_4conn.kicad_pcb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]
2016-09-05 sample received, confirmed awesome :)
    - added photos of 2nd batch
    - sma fit perfectly
    - minimal filing of breaktabs between panels
    - great fit of USB and DC plug combo
2016-09-10 0v5 version
    add 4 connector version
    move screw holes according found datasheet, hopefully more accurate
    board outline is "improved"
    fixes bug #10
    [BOM_76x35.xlsx, Front_Panel_76x35.kicad_pcb, Front_Panel_76x35_4conn.kicad_pcb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]
2016-09-11 qfix
    - #9 documents
    - USB and PWR cutout displacement for 0.15 mm
    [Front_Panel_76x35.kicad_pcb, Rear_Panel_76x35.kicad_pcb]
2016-09-24 3rd batch ready for fab house
    Gerber output produced
    Combined into a panel
    Added small holes on backside for "ventilation" #7
    Naming is consistent with current LimeSDR boards W, L, H order for TX #2
    Text stays on Silkscreen for now #8
    [Front_Panel_76x35-B.Cu.gbl, Front_Panel_76x35-B.Mask.gbs, Front_Panel_76x35-B.SilkS.gbo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]
2016-09-25 add 3d models in .wrl
    used @2ftg .step models and imported them into FreeCAD
    added .wrl for Rear panels and hole plugs
    [LimeSDR_USB.FCStd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]
2016-10-21 Fits great :+1:
    [LimeSDR_1v2_BOMr1.xls, LimeSDR_1v2s_BOMr2.xls]
2016-10-30 update of rear panel, 0v6
    suggestions from #12 and #15 taken into account, also because of #14
    [55307XXF.stp, LimeSDR_USB.FCStd, Rear_Panel_76x35.kicad_pcb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]
2016-11-04 New Gerbers for 0v6
    [Rear_Panel_76x35-B.Cu.gbl, Rear_Panel_76x35-B.Mask.gbs, Rear_Panel_76x35-B.SilkS.gbo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]
2016-11-12 .xlsx -> .csv for 0v6
    [BOM_76x35.csv]
2017-07-24 Move files from: hardware/plug/1v2/enclosure to : hardware/enclosure because all versions, so far, are taken into account (plug/socket, 1v2/1v4)
    [1.27_to_2.54_adapter.kicad_pcb, 1.27_to_2.54_adapter.sch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]
2017-07-24 Design files for version 1v0, which is currently sold as a KIT on eBay updated main README.md empty Instructions.md for linking
    [BSO_M3_5mm.FCStd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]
2017-07-29 additon: fan check
2018-01-07 Clean repository, archive
    [1.27_to_2.54_adapter.kicad_pcb, 1.27_to_2.54_adapter.sch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]
